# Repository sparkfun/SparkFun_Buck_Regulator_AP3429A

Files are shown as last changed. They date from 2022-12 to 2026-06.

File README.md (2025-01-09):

SparkFun AP3429A Buck Regulator Breakouts
========================================

<p align="center">
  <a href="https://github.com/sparkfun/SparkFun_Buck_Regulator_AP3429A/issues" alt="Issues">
    </a>
  <a href="https://github.com/sparkfun/SparkFun_Buck_Regulator_AP3429A/actions" alt="Actions">
    </a>
  <a href="https://github.com/sparkfun/SparkFun_Buck_Regulator_AP3429A/blob/main/LICENSE.md" alt="License">
    </a>
  <a href="https://twitter.com/intent/follow?screen_name=sparkfun">
    </a>
</p>

| [3.3V Buck Regulator (COM-21337)](https://www.sparkfun.com/products/21337) | [1.8V Buck Regulator (COM-21338)](https://www.sparkfun.com/products/21338) |
| --- | --- |
| SparkFun Buck Regulator Breakout - 3.3V (AP3429A) (https://www.sparkfun.com/products/21337) | SparkFun Buck Regulator Breakout - 1.8V (AP3429A) (https://www.sparkfun.com/products/21338) |

These buck regulator boards feature the AP3429A from [Diodes Inc.](https://www.diodes.com/), a 2A DC-DC buck converter with a wide input voltage range of 2.7V to 5.5V. The boards are configured to provide a regulated **3.3V** or **1.8V** output, which is controlled by an `EN` *(enable)* pin and indicated by a red power LED. A pre-assembled screw terminal and 0.1" spaced PTH pins are available to connect the input and output power of the boards. Additionally, there is the option to solder on a [barrel jack](https://www.sparkfun.com/products/119) for an [external power supply](https://www.sparkfun.com/categories/308). To dissipate excess heat, a copper pad is provided to attach a heat sink to the bottom of the board.

*The primary differences between these boards are their regulated output voltage (**1.8V** and **3.3V**) and the configured UVLO (**2.7V** and **3.9V**, respectively).*

Repository Contents
-------------------

* **[/docs](/docs/)** - Online documentation files
    * [board_files](/docs/board_files/) - Files for the product design
        * [Eagle design files](/docs/board_files/eagle_files.zip) (.zip)
        * [Schematic](/docs/board_files/schematic.pdf) (.pdf)
        * [Dimensions](/docs/board_files/dimensions.pdf) (.pdf)
    * [component_documentation](/docs/component_documentation/) - Datasheets for hardware components
    * [img/hookup_guide/](/docs/img/hookup_guide/) - Images for hookup guide documentation
* **[/Hardware](/Hardware/)** - Eagle design files (.brd, .sch)

Documentation
--------------
* **[Hookup Guide (mkdocs)](http://docs.sparkfun.com/SparkFun_Buck_Regulator_AP3429A/)** - Hookup Guide for the AP3429A Buck Regulator Breakouts

Product Variants
----------------
* **AP63357** - 5V Buck Regulators
    * COM-21255: [SparkFun Buck Regulator Breakout - 5V (AP63357DV)](https://www.sparkfun.com/products/21255)
    * COM-21256: [SparkFun BabyBuck Regulator Breakout - 5V (AP63357DV)](https://www.sparkfun.com/products/21256)
* **AP63203** - 3.3V Buck Regulators
    * COM-18356: [SparkFun Buck Regulator Breakout - 3.3V (AP63203)](https://www.sparkfun.com/products/18356)
    * COM-18357: [SparkFun BabyBuck Regulator Breakout - 3.3V (AP63203)](https://www.sparkfun.com/products/18357)
* **AP3429A** - 3.3V & 1.8V Buck Regulators
    * COM-21337: [SparkFun Buck Regulator Breakout - 3.3V (AP3429A)](https://www.sparkfun.com/products/21337)
    * COM-21338: [SparkFun Buck Regulator Breakout - 1.8V (AP3429A)](https://www.sparkfun.com/products/21338)

Version History
---------------
* [v01](https://github.com/sparkfun/SparkFun_Buck_Regulator_AP3429A/releases/tag/v01) - Initial Release

License Information
-------------------

This product is _**open source**_! 

Please review the LICENSE.md file for license information. 

If you have any questions or concerns about licensing, please contact technical support on our [SparkFun forums](https://forum.sparkfun.com/viewforum.php?f=152).

Distributed as-is; no warranty is given.

- Your friends at SparkFun.

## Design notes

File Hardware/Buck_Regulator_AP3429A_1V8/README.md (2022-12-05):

SparkFun <PRODUCT NAME> Design Files
=====================================

The .sch and .brd files hare are Eagle CAD schematic and PCB design files from SparkFun Electronics.
A freeware version of Autodesk Eagle can be found [here](https://www.autodesk.com/products/eagle/free-download).

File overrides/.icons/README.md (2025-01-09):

.icons directory
====================
This folder should contain branding logos for the product documentation

## General Images
- `sfe-logo.svg` - SparkFun flame logo
- `kicad-primary.svg` - Full KiCad logo

## Directory
- `logo` - Other available logos

## SVG Optimizer
- [Remove meta data from svg](https://jakearchibald.github.io/svgomg/)

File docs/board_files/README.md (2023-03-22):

board_files directory
====================

1. A `dimensions*.pdf` file containing the boards' measurements.
2. A `schematic*.pdf` file containing the boards' schematics.
3. An `eagle_files*.zip` folder containing the Eagle CAD schematics (`*.sch`) and PCB design (`*.brd`) files.
    * A freeware version of Autodesk Eagle can be found [here](https://www.autodesk.com/products/eagle/free-download).

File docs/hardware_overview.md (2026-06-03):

---
icon: material/cog
---

## Board Dimensions

The board dimensions are illustrated in the drawing below; the listed measurements are in inches.

<figure markdown>
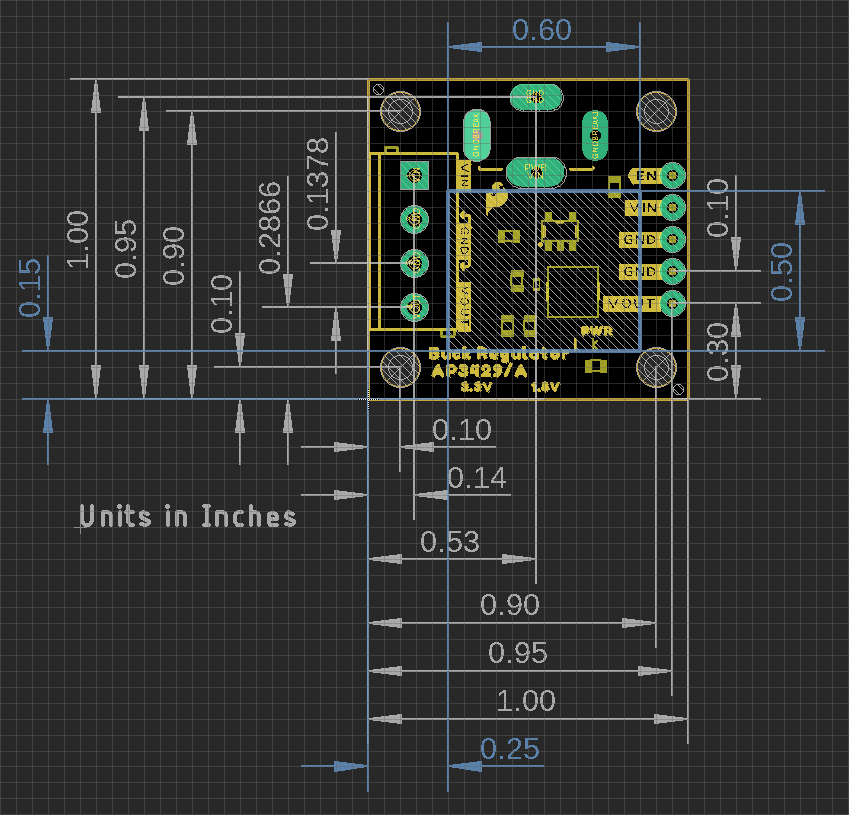
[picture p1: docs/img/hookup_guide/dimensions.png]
Board Dimensions

<figcaption markdown>
[Board dimensions (PDF)](../board_files/dimensions.pdf) for the AP3429A Buck Regulator breakout boards, in inches.
</figcaption>
</figure>

??? tip "Need more measurements?"
	For more information about the board's dimensions, users can download the [eagle files](../board_files/eagle_files.zip) for the board. These files can be opened in Eagle and additional measurements can be made with the dimensions tool.

	??? info ":octicons-download-16:{ .heart } Eagle - Free Download!"
		Eagle is a [CAD]("computer-aided design") program for electronics that is free to use for hobbyists and students. However, it does require an account registration to utilize the software.

		<article style="text-align: center;" markdown>
		[Download from<br>:autodesk-primary:{ .enlarge-logo }](https://www.autodesk.com/products/eagle/free-download "Go to downloads page"){ .md-button .md-button--primary width="250px" }
		</article>
	
	??? info ":straight_ruler: Dimensions Tool"
		This video from Autodesk demonstrates how to utilize the dimensions tool in Eagle, to include additional measurements:

		<article style="text-align: center;" markdown>
		<div class="video">
		<iframe src="https://www.youtube.com/embed/dZLNd1FtNB8" title="EAGLE Dimension Tool" frameborder="0" allow="accelerometer; autoplay; clipboard-write; encrypted-media; gyroscope; picture-in-picture" allowfullscreen></iframe>
		</div>
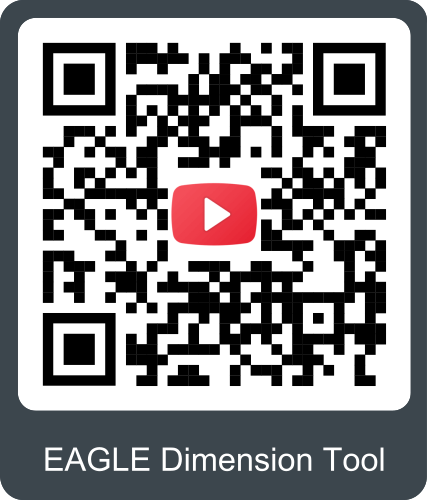
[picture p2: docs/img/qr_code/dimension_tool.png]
QR code to play video
		
		</article>

## Power

Users are provided with [PTH](https://en.wikipedia.org/wiki/Through-hole_technology "Plated Through Holes") to connect their external power supply, the output voltage from the board, and the [`EN`](#power-control "Enable") power control pin for the buck regulator. The AP3429A buck regulator has an input voltage range is **2.7V** to **5.5V**. Each board has a different regulated output voltage (**1.8V** or **3.3V**) and input voltage range. *(These are step-down DC/DC converters and cannot step-up or boost the voltage output.)*

<figure markdown>
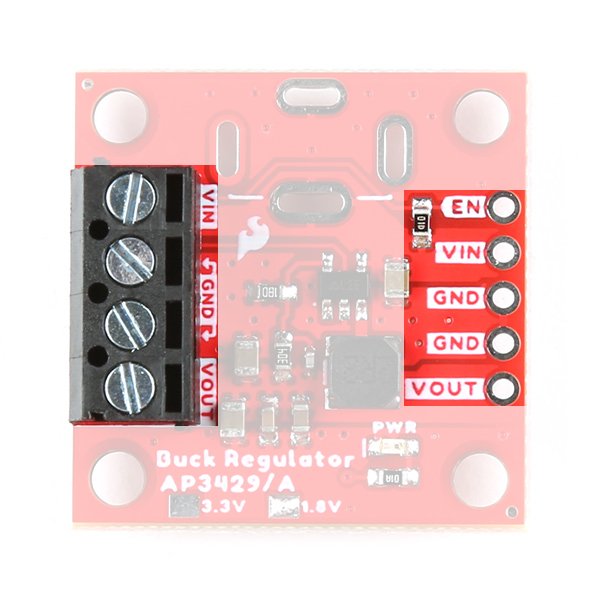
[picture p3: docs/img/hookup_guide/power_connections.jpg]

<figcaption markdown>
The power connections on the AP3429A Buck Regulator Breakout boards.
</figcaption>
</figure>

Below, is a general summary of the circuitry on the board:

* **`VIN`** - Power supply input
    * 1.8V Buck Regulator: **<span style="color:red">2.7V</span> to 5.5V**
    * 3.3V Buck Regulator: **<span style="color:green">3.9V</span> to 5.5V**
* **`EN`** - Enables the power output of the board
	* Has an input voltage range up to **5.5V**
	* Must be pulled `HIGH` above **1.5V** to enable the power output. Otherwise, if pulled `LOW` below 0.4V, the device shuts down.
* **`VOUT`** - Regulated 1.8V or 3.3V output *(up to 2A)*
* **`GND`** - The common ground or the 0V reference for the board

!!! info
	For more details, users can reference the [schematic](../board_files/schematic.pdf) and the [datasheets of the individual components](../resources/#hardware-component-documentation) in the power circuitry.

??? tip "Maximum Load Current"
	While the IC is rated up to 2A, we were able to squeeze a little extra juice for a maximum load of ~2.2A. Anything near 2.4A, the board will start to struggle and automatically shut down.
	
	***Disclaimer:** We don't recommend that users expect to be able to load the boards with a maximum 2.2A, as we are not sure how this may affect the lifespan of the board. We just want users to know that they may have an extra margin of safety on their peak load.* 

??? tip "Quiescent Current Draw"
    Users should expect a nominal quiescent current draw of ~90&micro;A from the board. For a lower quiescent current, users can disable the power output and/or modify the board by removing the pull-up resistor on the [`EN`](#power-control "enable") pin.

	<div class="grid cards" markdown>

	-	Measured Values

		---

		<table style="text-align: center;" markdown>
		<tr markdown>
		<td rowspan="2" align="center" style="vertical-align:middle;" markdown>
		Input<br>Voltage (V)
		</td>
		<td colspan="2" align="center" style="vertical-align:middle;" markdown>
		I~q~ (&micro;A)<br>*Power Disabled*
		</td>
		<td colspan="2" align="center" markdown>
		I~q~ (&micro;A)<br>*Power Enabled*
		</td>
		</tr>
		<tr markdown>
		<td align="center" markdown>**1.8V**</td>
		<td align="center" markdown>**3.3V**</td>
		<td align="center" markdown>**1.8V**</td>
		<td align="center" markdown>**3.3V**</td>
		</tr>
		<tr markdown>
		<td align="center" markdown>5.0</td>
		<td markdown>49.34</td>
		<td markdown>49.58</td>
		<td markdown>85.15</td>
		<td markdown>97.48</td>
		</tr>
		<tr markdown>
		<td align="center" markdown>4.5</td>
		<td markdown>44.60</td>
		<td markdown>44.81</td>
		<td markdown>83.32</td>
		<td markdown>96.00</td>
		</tr>
		<tr markdown>
		<td align="center" markdown>4.2</td>
		<td markdown>41.51</td>
		<td markdown>41.71</td>
		<td markdown>82.64</td>
		<td markdown>95.27</td>
		</tr>
		<tr markdown>
		<td align="center" markdown>3.9</td>
		<td align="center" markdown>---</td>
		<td markdown>38.70</td>
		<td align="center" markdown>---</td>
		<td markdown>95.03</td>
		</tr>
		<tr markdown>
		<td align="center" markdown>3.7</td>
		<td markdown>36.60</td>
		<td markdown>36.76</td>
		<td markdown>81.88</td>
		<td markdown>94.87</td>
		</tr>
		<tr markdown>
		<td align="center" markdown>3.3</td>
		<td markdown>32.70</td>
		<td markdown>32.84</td>
		<td markdown>81.23</td>
		<td markdown>338.12</td>
		</tr>
		<tr markdown>
		<td align="center" markdown>3.0</td>
		<td markdown>29.82</td>
		<td align="center" markdown>N/A</td>
		<td markdown>80.59</td>
		<td align="center" markdown>N/A</td>
		</tr>
		<tr markdown>
		<td align="center" markdown>2.7</td>
		<td markdown>27.06</td>
		<td align="center" markdown>N/A</td>
		<td markdown>79.58</td>
		<td align="center" markdown>N/A</td>
		</tr>
		</table>

		*The values in the table above, were measured with a [Power Profiler Kit II](https://www.nordicsemi.com/Products/Development-hardware/Power-Profiler-Kit-2) and averaged over a 10s period.*

	-	Pull-Up Resistor Modification

		---

		<figure markdown>
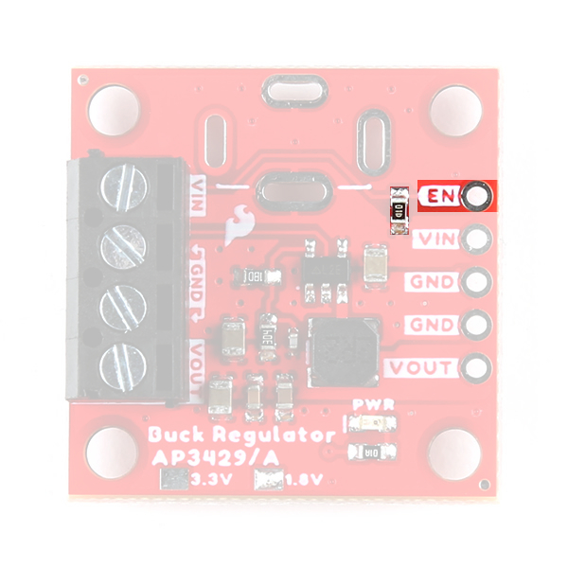
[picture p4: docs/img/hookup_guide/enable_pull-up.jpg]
		
		<figcaption markdown>
		Pull-up resistor on the AP3429A Buck Regulator Breakout boards.
		</figcaption>
		</figure>
		
		!!! danger
			Modifying a board to remove the pull-up resistor, requires advanced soldering skills. Users should **not** attempt this modification unless it is absolutely, necessary and they are confident in their skills because the board can be permanently damaged.

	</div>

### Power Connections

There are several options available for users to connect power to and from their AP3429A buck regulator breakout board.

<article style="text-align: center;" markdown>

| Input Options  | Output Power | Enable Pin |
| :--- | :--- | :--- |
| <ul><li>PTH Pins</li><li>Screw Terminal</li><li>Barrel Jack</li></ul> | <ul><li>PTH Pins</li><li>Screw Terminal</li></ul> | <ul><li>PTH Pins</li></ul> |

</article>

#### PTH Pins

Five [PTH](https://en.wikipedia.org/wiki/Through-hole_technology "Plated Through Holes") pins are provided for an external power supply, the output voltage from the board, and the [`EN`](#power-control "enable") power control pin. The holes are spaced 0.1", to be compatible with [headers](https://www.sparkfun.com/categories/381 "Click here for a full selection of our available headers") and [breadboards](https://www.sparkfun.com/categories/302 "Click here for a full selection of our available breadboards").

<figure markdown>
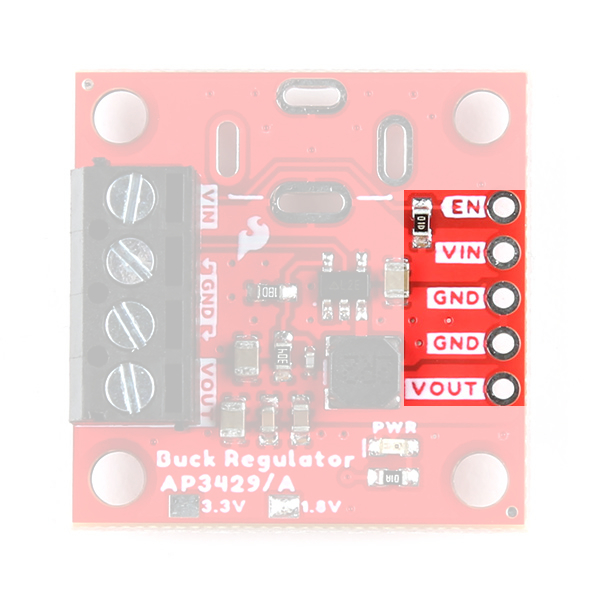
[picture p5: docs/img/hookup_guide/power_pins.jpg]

<figcaption markdown>
The PTH power pins on the AP3429A Buck Regulator Breakout boards.
</figcaption>
</figure>

#### Screw Terminals

A screw terminal is provided for users, as a non-permanent solution, to easily connect wires to the board.

!!! info "Compatible Wire Sizes"
	The screw terminal is compatible with wire sizes from **26AWG** to **16AWG**.

<figure markdown>
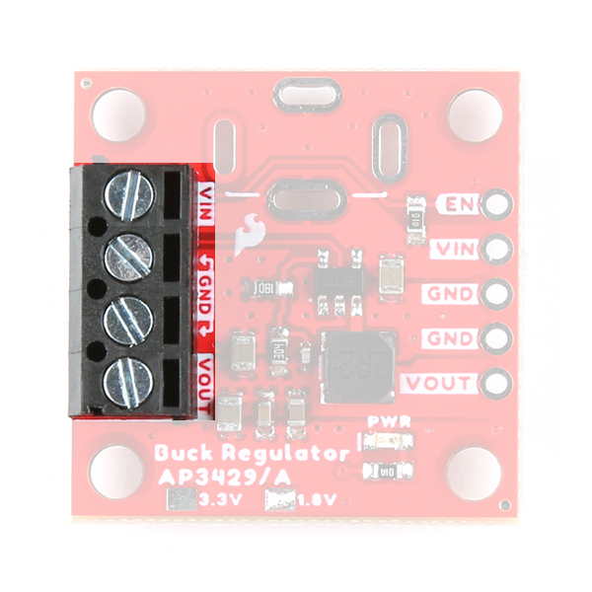
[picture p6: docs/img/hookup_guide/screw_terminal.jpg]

<figcaption markdown>The screw terminal on the AP3429A Buck Regulator Breakout boards.</figcaption>
</figure>

#### Barrel Jack

PTH *(slots)* are provided for users to add a [barrel jack connector](https://www.sparkfun.com/products/119) to the top or bottom of the board. This provides users with an alternative method to connect a power supply to their board.

!!! info "Barrel Jack Size"
	Our recommended [barrel jack connector](https://www.sparkfun.com/products/119) is a 5.5mm barrel jack.

<div class="grid cards" markdown>

-   <figure markdown>
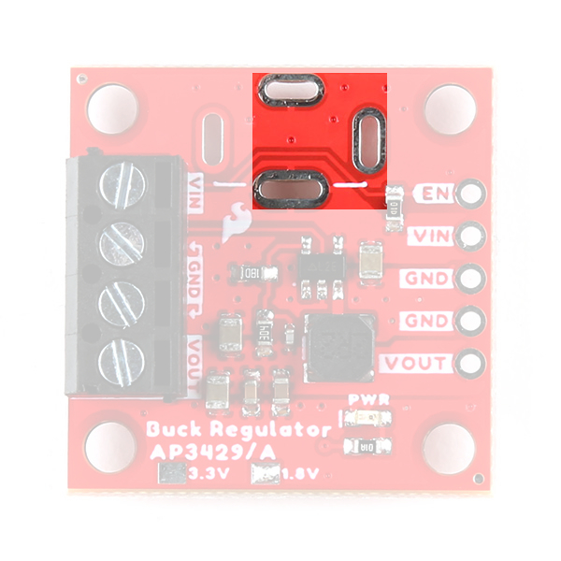
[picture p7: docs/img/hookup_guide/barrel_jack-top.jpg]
	
	<figcaption markdown>
    The plated slots for a barrel jack connector on the top side of the AP3429A Buck Regulator Breakout boards.
    </figcaption>
	</figure>

-   <figure markdown>
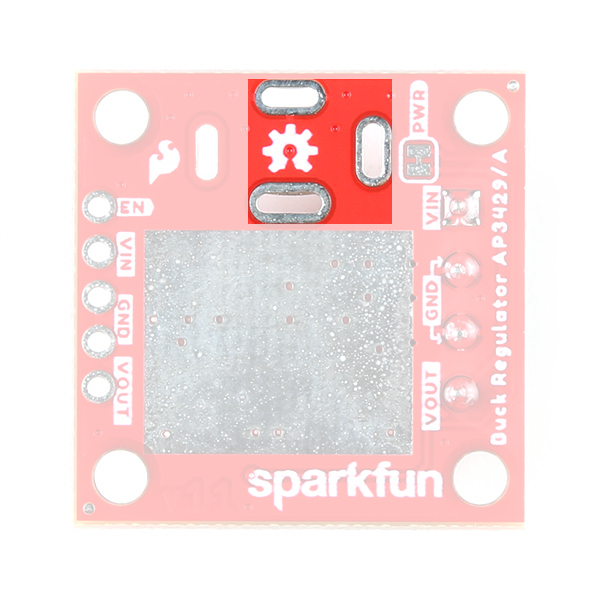
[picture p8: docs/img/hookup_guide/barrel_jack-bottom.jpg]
	
	<figcaption markdown>
	The plated slots for a barrel jack connector on the bottom side of the AP3429A Buck Regulator Breakout boards.
	</figcaption>
	</figure>

</div>

### Power LED

The red, power (`PWR`) LED will light up when the switching power output is enabled. However, the LED can be disabled for low-power applications by cutting the [jumper](#jumper).

<figure markdown>
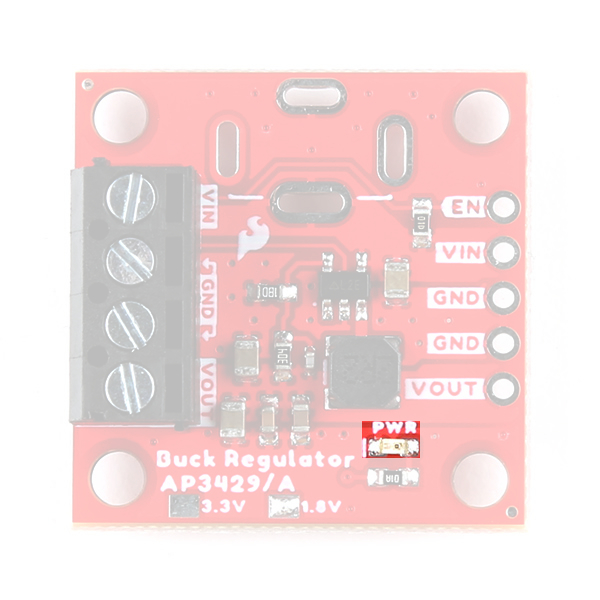
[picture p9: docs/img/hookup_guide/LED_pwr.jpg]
Power LED

<figcaption markdown>
The `PWR` status LED indicator for the AP3429A Buck Regulator Breakout boards.
</figcaption>
</figure>

### Power Control

There is an enable pin (`EN`) to control the output voltage *(i.e. on/off)*, with a typical threshold voltage of **1.5V** and a range up to **5.5V**

* Users should pull the `EN` pin high *(above 1.5V)* to enable the switching power output and pull the pin low *(below 0.4V)* to disable it.
	* Users can connect the `EN` pin to `VIN` to override the [UVLO]("Undervoltage Lockout") threshold.

!!! info "Default Configuration"
	On our boards, the `EN` pin is pulled `HIGH` and the power output from the board is enabled by default.

<figure markdown>
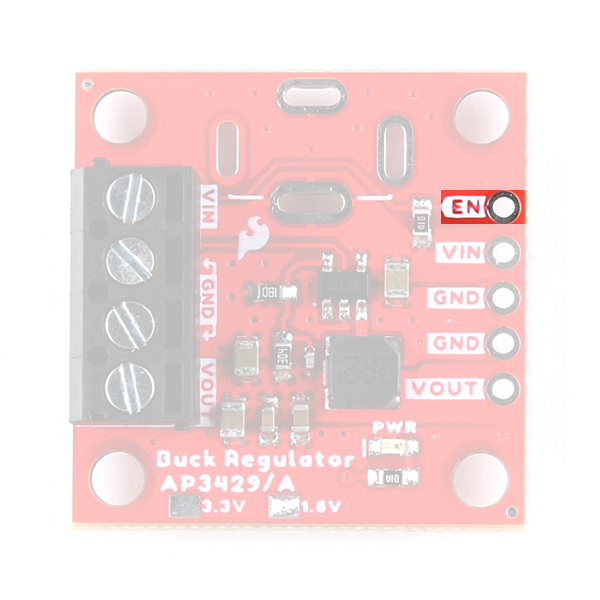
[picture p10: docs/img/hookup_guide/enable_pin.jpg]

<figcaption markdown>
Enable pin on the AP3429A Buck Regulator Breakout boards.
</figcaption>
</figure>

## :fontawesome-solid-microchip:&nbsp;AP3429A

The [AP3429A](../component_documentation/AP3429A.pdf) from [Diodes Incorporated](https://www.diodes.com/), is a 2A DC-DC buck converter with a wide input voltage range of 2.7V to 5.5V. Under a no-load condition, the quiescent current is 90&micro;A; and when disabled, the device shutdown supply current is less than 1&micro;A.

<div class="grid cards" markdown>

-   Features:

    * VIN: 2.7V to 5.5V
    * VOUT: 0.6V to VIN
    * 2A Continuous Output Current
    * 90&micro;A No-Load Quiescent Current
    * 1MHz Switching Frequency
    * Protection Circuitry
        * Undervoltage Lockout (UVLO)
        * Input Overvoltage Protection
        * Over Current Protection
            * Cycle-by-Cycle Peak Current Limit
        * Thermal Shutdown

-	<figure markdown>
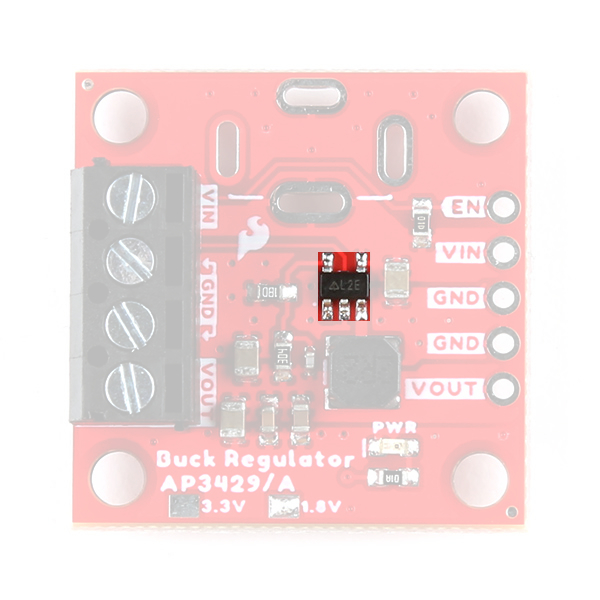
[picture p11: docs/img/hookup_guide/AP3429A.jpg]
	
	<figcaption markdown>
	AP3429A chip on the AP3429A Buck Regulator Breakout boards.
	</figcaption>
	</figure>

</div>

!!! info
	For more details, please refer to the [AP3429A datasheet](../component_documentation/AP3429A.pdf) and [application note](../component_documentation/AN_AP3428.pdf).

??? info "Power Efficiency"
	Users should expect a power efficiency close to the chart presented in the [datasheet](../component_documentation/AP3429A.pdf) *(i.e. ~80% with smaller loads and up to +90% with larger loads)*. It should be noted that the efficiency varies with the load current and cooling.

	<figure markdown>
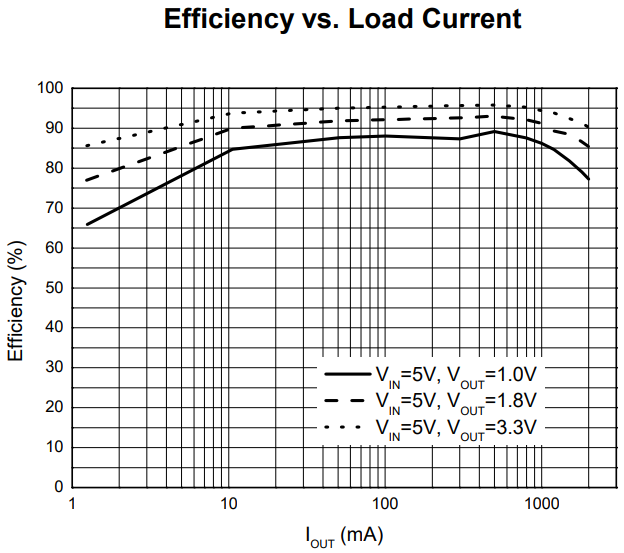
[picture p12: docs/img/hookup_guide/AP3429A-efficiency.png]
	
	<figcaption markdown>
	Figure from the [datasheet](../component_documentation/AP3429A.pdf).
	</figcaption>
	</figure>

??? info "Circuit Protection"
	The AP3429A features the following circuit protections:

	=== "Undervoltage Lockout"
		We have found the undervoltage lockout to trigger ~2.7V for the 1.8V breakout and ~3.9V for the 3.3V breakout board.
	
	=== "Over Current Protection"
		
		* If the peak current is higher than the current limit threshold, it will enter cycle-by-cycle current limit mode.
		* If short is detected, when the feedback voltage (V~FB~) drops under 0.3V, the AP3429 will turn off power output until the `VIN` or `EN` is cycled again to release it.
			* Once V~FB~ rises over 0.3V, the AP3429A automatically recovers to normal operation.
	
	=== "Over Voltage Protection"
		* **Output:** When `VOUT` exceeds 120% of the regulation level, the output power will be disabled until `VIN` or `EN` is cycled.
		* **Input:** When the input voltage is near 6.25V, the IC will shut down until the input voltage drops back down below 6V.

### Output Voltage Configuration

The output voltage from the AP3429A, is determined by the voltage divider on the feedback loop, as discussed in the [application note](../component_documentation/AN_AP3428.pdf).

??? note "Application Note"
	While the [application note](../component_documentation/AN_AP3428.pdf) only lists the AP3428 buck converter, Diodes Incorporated has assured us that it is still applicable to the AP3429A.

$$
V_{OUT} =  0.6 * \frac{ (R_1 + R_2) }{ R_2 }
$$

Where, R~1~ and R~2~ are the resistors in the feedback loop:

<figure markdown>
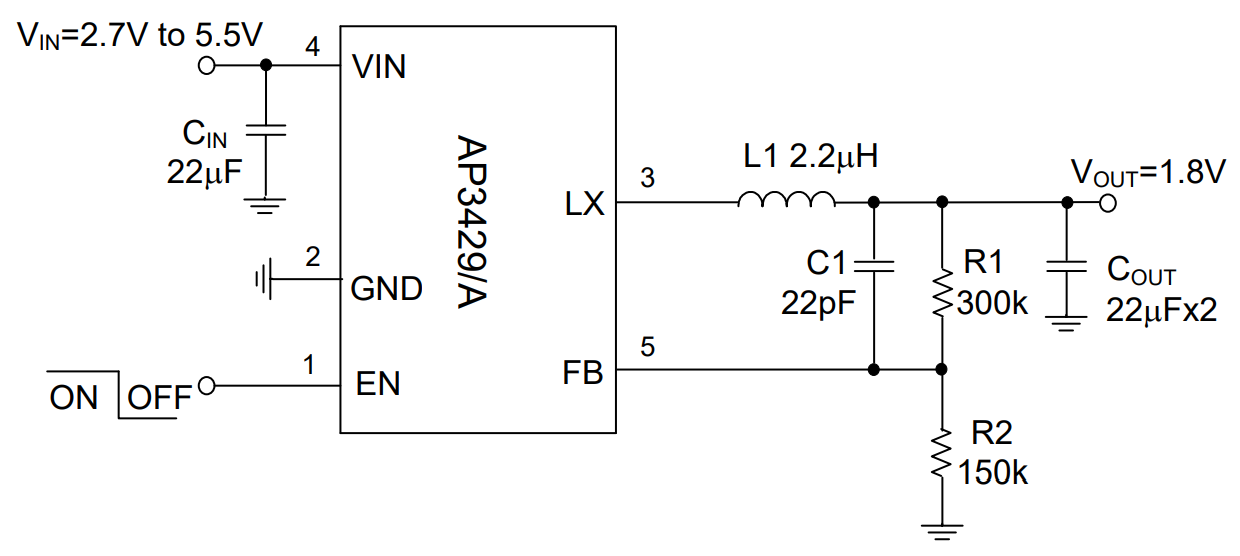
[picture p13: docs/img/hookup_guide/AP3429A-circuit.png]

<figcaption markdown>
Example circuit for the AP3429A.
</figcaption>
</figure>

## Output Voltage Indicator

Since it would be difficult to differentiate the voltage output based on the small SMD parts, we provide a simple indicator for the configured output voltage of each board.

<div class="grid cards" markdown>

-   <figure markdown>
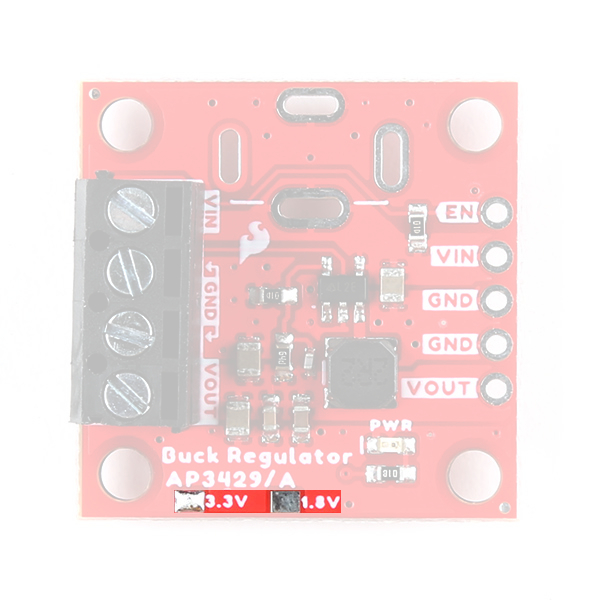
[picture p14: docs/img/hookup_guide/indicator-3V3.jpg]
	
	<figcaption markdown>
    The output voltage indicator for the **3.3V** Buck Regulator Breakout.
    </figcaption>
	</figure>

-   <figure markdown>
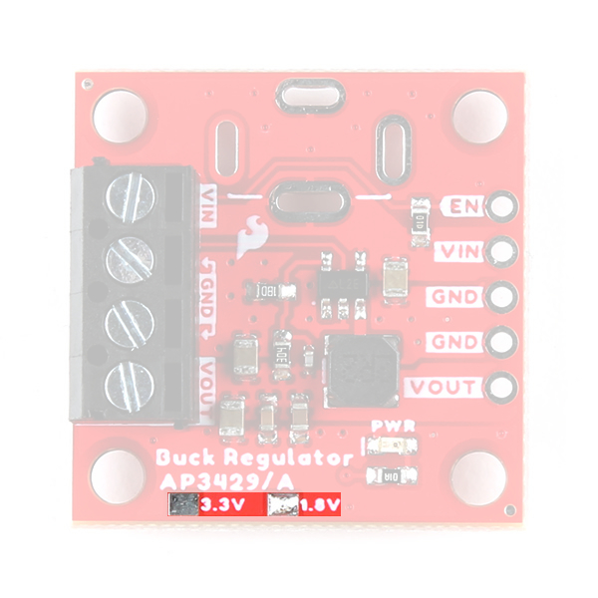
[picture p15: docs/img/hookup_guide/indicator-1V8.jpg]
	
	<figcaption markdown>
	The output voltage indicator for the **1.8V** Buck Regulator Breakout.
	</figcaption>
	</figure>

</div>

## Heat Sink Pad

A 0.5" x 0.6" platted copper pad is provided on the back of the boards, where users can add a heat sink to dissipate excess heat generated by the AP3429A. The pad can accommodate the [copper heatsink](https://www.sparkfun.com/products/18704) in our catalog.

??? info "Thermal Shutdown Temperature"
	The AP329A has a 160&deg;C (320&deg;F) thermal shutdown temperature. The AP3429A will restart automatically when the junction temperature decreases to +130°C.

<figure markdown>
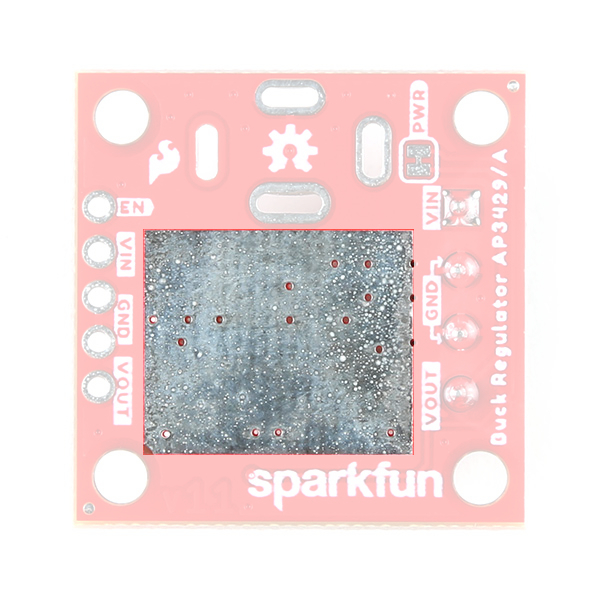
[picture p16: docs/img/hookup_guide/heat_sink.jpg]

<figcaption markdown>
Heat sink pad on the back of the AP3429A Buck Regulator Breakout boards.
</figcaption>
</figure>

??? tip "Thermal Characteristics"
	Below are charts depicting the thermal performance of the AP3429A Buck Regulator Breakout boards that users should expect. These values were measured at 200mA steps for input voltages between 4 - 5.5V.

	=== "1.8V w/o Heatsink"
		<figure markdown>
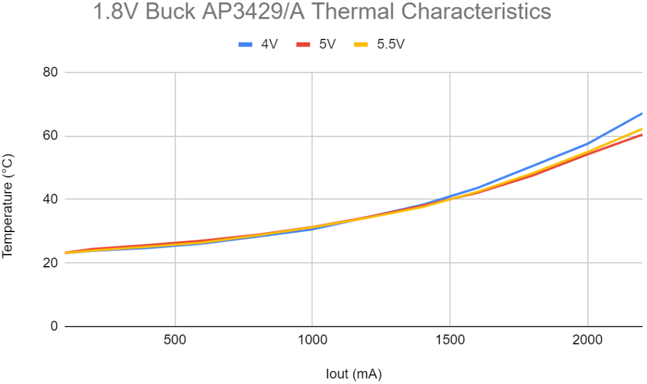
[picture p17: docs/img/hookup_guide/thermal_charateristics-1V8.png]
		
		<figcaption markdown>
		Thermal characteristics of the 1.8V Buck Regulator Breakout board without a heatsink.
		</figcaption>
		</figure>
	
	=== "1.8V w/ Heatsink"
		<figure markdown>
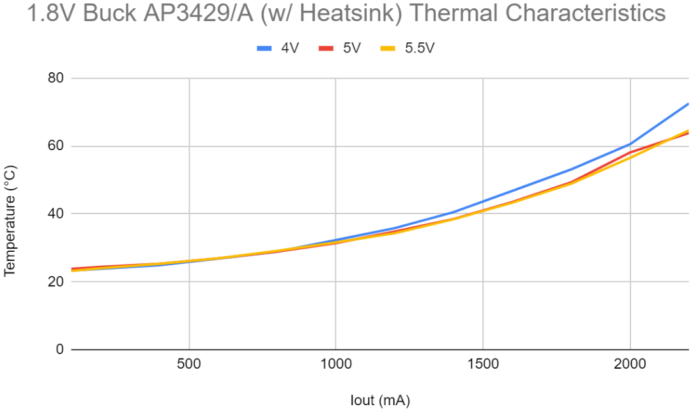
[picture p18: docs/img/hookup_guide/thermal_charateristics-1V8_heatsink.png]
		
		<figcaption markdown>
		Thermal characteristics of the 1.8V Buck Regulator Breakout board with a heatsink.
		</figcaption>
		</figure>

	=== "3.3V w/o Heatsink"
		<figure markdown>
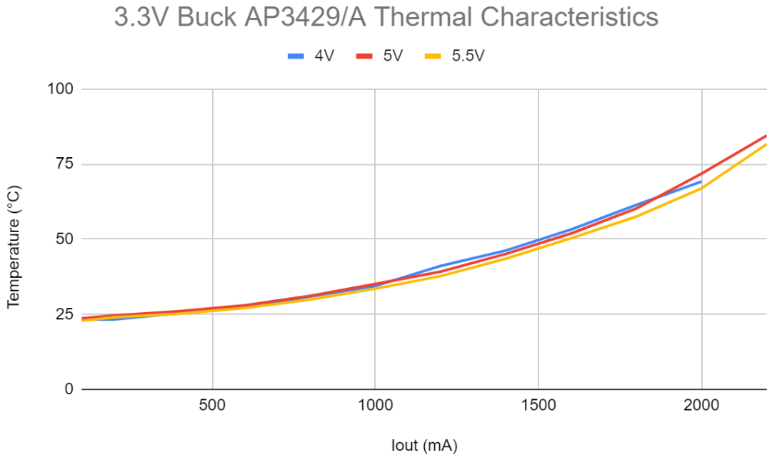
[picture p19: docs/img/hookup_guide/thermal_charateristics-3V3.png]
		
		<figcaption markdown>
		Thermal characteristics of the 3.3V Buck Regulator Breakout board without a heatsink.
		</figcaption>
		</figure>

	=== "3.3V w/ Heatsink"
		<figure markdown>
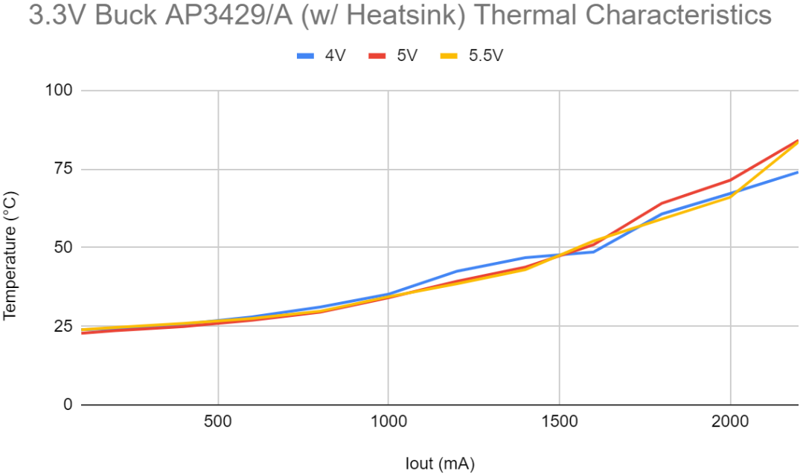
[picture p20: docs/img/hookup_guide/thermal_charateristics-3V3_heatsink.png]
		
		<figcaption markdown>
		Thermal characteristics of the 3.3V Buck Regulator Breakout board with a heatsink.
		</figcaption>
		</figure>

## Jumper

??? note "Never modified a jumper before?"
	Check out our <a href="https://learn.sparkfun.com/tutorials/664">Jumper Pads and PCB Traces tutorial</a> for a quick introduction!
	<p align="center">
		<a href="https://learn.sparkfun.com/tutorials/664">How to Work with Jumper Pads and PCB Traces<br>
		Tutorial's thumbnail</a>
	</p>

There is a jumper on the back of the board that can be used to easily modify a hardware connection on the board.

* **PWR** - This jumper can be used to remove power to the `PWR` LED.

<figure markdown>
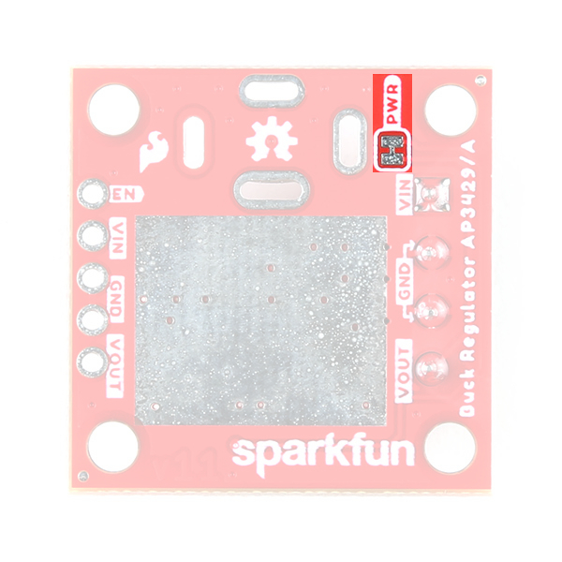
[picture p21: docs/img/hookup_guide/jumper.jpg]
Jumpers

<figcaption markdown>
The LED jumper on the back of the AP3429A Buck Regulator Breakout boards.
</figcaption>
</figure>

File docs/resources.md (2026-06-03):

## Product Resources

<section class="grid cards show" style="grid-template-columns: repeat(auto-fit,minmax(8rem,1fr));" markdown>

- **Composite (Both Boards)**

    ---

    * :sfe-logo: [Product Category](https://www.sparkfun.com/categories/tags/buck-)
    * :fontawesome-solid-file-pdf: [Board Dimensions](./board_files/dimensions.pdf)
    * Component Documentation
        * :fontawesome-solid-file-pdf: [AP3429A Datasheet](./component_documentation/AP3429A.pdf)
        * :fontawesome-solid-file-pdf: [Application Note](./component_documentation/AN_AP3428.pdf)
    * :material-folder-cog: Design Files:
        * :fontawesome-solid-file-pdf: [Schematic](./board_files/schematic.pdf)
        * :material-folder-zip: [Eagle Files](./board_files/eagle_files.zip)
    * :material-github: [Hardware Repo](https://github.com/sparkfun/SparkFun_Buck_Regulator_AP3429A)

- **3.3V Buck Regulator Breakout - (AP3429A)**

    ---

    * :sfe-logo: [Product Page](https://www.sparkfun.com/products/21337)
    * :material-folder-cog: Design Files:
        * :fontawesome-solid-file-pdf: [Schematic](./board_files/schematic-Buck3V3.pdf)
        * :material-folder-zip: [Eagle Files](./board_files/eagle_files-Buck3V3.zip)

- **1.8V Buck Regulator Breakout - (AP3429A)**

    ---

    * :sfe-logo: [Product Page](https://www.sparkfun.com/products/21338)
    * :material-folder-cog: Design Files:
        * :fontawesome-solid-file-pdf: [Schematic](./board_files/schematic-Buck1V8.pdf)
        * :material-folder-zip: [Eagle Files](./board_files/eagle_files-Buck1V8.zip)

</section>

### Additional Resources

* [DC/DC Converter Product Category](https://www.sparkfun.com/categories/tags/dc-dc-converter)
* :material-account-supervisor: [SparkFun Technical Assistance](https://www.sparkfun.com/technical_assistance)

## 🏭&nbsp;Manufacturer's Resources
Diodes Incorporated also provides great resources for the AP3429A Buck Regulator:

* [AP3429A Product Page](https://www.diodes.com/part/view/AP3429)
    * :material-file-document-multiple: [Technical Documentation](ps://www.diodes.com/part/view/AP3429/#tab-details)
* :material-head-question: [Technical Support Page](https://www.diodes.com/about/contact-us/technical-support/)

<article style="text-align: center;" markdown>
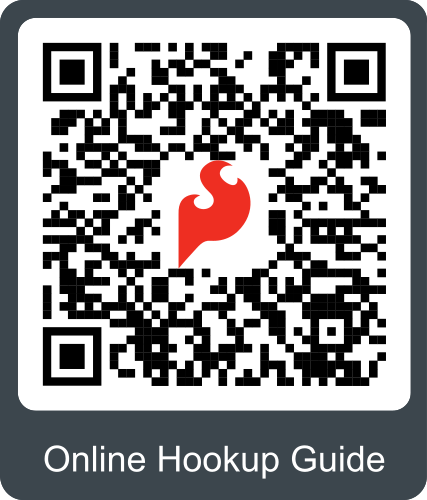
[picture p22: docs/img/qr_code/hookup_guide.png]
QR code to the hookup guide

</article>

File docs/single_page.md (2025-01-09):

---
hide:
  - navigation
  - toc
icon: fontawesome/solid/scroll
---

--8<-- "./docs/getting_started.md:5"

# Hardware Overview
--8<-- "./docs/hardware_overview.md:5"

# Hardware Assembly
--8<-- "./docs/hardware_assembly.md:5"

# Troubleshooting Tips
--8<-- "./docs/troubleshooting_tips.md:5"

# Test Setup
--8<-- "./docs/load_test.md:5"

# Resources
--8<-- "./docs/resources.md"

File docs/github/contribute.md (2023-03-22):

# Contribute: Make an Augmentation!
Spot an improvement opportunity? Feel free to contribute to our open-source design and documentation. 

## :material-file-document-multiple:&nbsp;Improve our Documentation
All of this documentation can be modified by you! Please help us make it better.

* These pages are contained in the [`docs` folder](https://github.com/sparkfun/SparkFun_Buck_Regulator_AP3429A/tree/main/docs) of the [SparkFun AP3429A Buck Regulator repository](https://github.com/sparkfun/SparkFun_Buck_Regulator_AP3429A).

<!-- ### :material-source-pull:&nbsp;Submit a Correction -->
### Submit a Correction

1. With a GitHub account, [fork this repository](https://github.com/sparkfun/SparkFun_Buck_Regulator_AP3429A/fork).
2. Add your corrections or improvements to the markdown file.
3. File a pull request with your changes, and enjoy making the ~~words~~ ~~worlds~~ world a better place.
	* Once received, the documentation specialist will automatically be notified.
	* We will review your suggested improvements to make sure they are correct and fit within our documentation standards.

## :material-cog:&nbsp;Improve our Hardware Design
All of our designs are open-source! Please help us make it better.

* Our board design files are contained in the [`Hardware` folder](https://github.com/sparkfun/SparkFun_Buck_Regulator_AP3429A/tree/main/Hardware) of the [SparkFun AP3429A Buck Regulator repository](https://github.com/sparkfun/SparkFun_Buck_Regulator_AP3429A).

<!-- ### :material-source-pull:&nbsp;Submit a Design Enhancement -->
### Submit a Design Enhancement

1. With a GitHub account, [fork this repository](https://github.com/sparkfun/SparkFun_Buck_Regulator_AP3429A/fork).
2. Add your design augmentation(s)
3. File a pull request with your changes, and enjoy making the ~~words~~ ~~worlds~~ world a better place.
	1. Once received, the engineer in charge of the original design will automatically be notified.
	2. We will review your suggested improvement(s) to verify that they are within our board design standards and meet our product design requirements.
	3. If approved, we will flag these changes for our next board revision. Congrats! 🍻

		!!! info
			Even if your suggestion is accepted, these changes may not be immediately available for purchase. We may have to cycle through our current product inventory first.

## Contributors&nbsp;:clap:
Let's provide some recognition to the contributors for this project!

GitHub Contributors Image
<br>


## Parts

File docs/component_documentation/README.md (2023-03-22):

component_documentation directory
====================

A copy of the datasheets, user manuals, programming guides, etc. of the major electrical components on the board.

* DC-DC Buck Converter: [AP3429A](AP3429A.pdf) (PDF)
    * Application Note: [AN_AP3428](AN_AP3428.pdf) (PDF)
        * *Although the application note is listed for the AP3428, Diodes Inc. provided this document for configuring the output voltage of the AP3429A. The application note is interchangeable between the two ICs.*

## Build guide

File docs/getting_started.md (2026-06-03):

---
icon: material/book-open-page-variant
---

# Getting Started

!!! note
	The SparkFun Buck Regulator Breakout - [3.3V (AP3429A)](https://www.sparkfun.com/products/21337) and [1.8V (AP3429A)](https://www.sparkfun.com/products/21338) have similar features to our previous [buck regulators (AP63203 & AP63357)](https://www.sparkfun.com/categories/tags/buck-).

## Introduction
These boards feature the AP3429A from [Diodes Inc.](https://www.diodes.com/), a 2A step-down DC-DC converter with an input voltage range of 2.7V to 5.5V. They are configured to provide a regulated **3.3V** or **1.8V** output, which is controlled by an `EN` *(enable)* pin and indicated by a red power LED. A pre-assembled screw terminal and 0.1" spaced PTH pins are available to connect the input and output power of the boards. Additionally, there is the option to solder on a [barrel jack](https://www.sparkfun.com/products/119) for an [external power supply](https://www.sparkfun.com/categories/308). To dissipate excess heat, a 0.5" x 0.6" copper pad is provided to attach a heat sink to the bottom of the board.

<section class="grid cards col-2"markdown>

-	<a href="https://www.sparkfun.com/products/21337">
	**3.3V Buck Regulator Breakout - AP3429A**<br>
	**SKU:** COM-21337

	---

	<figure markdown>
	Product image
	</figure>
	</a>

	This board provides a regulated **3.3V** output with an input voltage range of **3.9V - 5.5V**.

	<article style="text-align: center;" markdown>
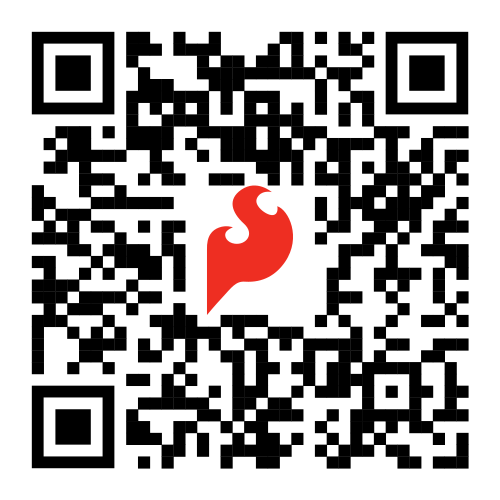
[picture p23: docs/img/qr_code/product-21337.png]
QR code to product page
	[&nbsp;&nbsp;&nbsp;Purchase from SparkFun :fontawesome-solid-cart-plus:{ .heart }](https://www.sparkfun.com/products/21337){ .md-button .md-button--primary }
	</article>

-	<a href="https://www.sparkfun.com/products/21338">
	**1.8V Buck Regulator Breakout - AP3429A**<br>
	**SKU:** COM-21338

	---

	<figure markdown>
	Product image
	</figure></a>

	This board provides a regulated **1.8V** output with an input voltage range of **2.7V - 5.5V**.

	<article style="text-align: center;" markdown>
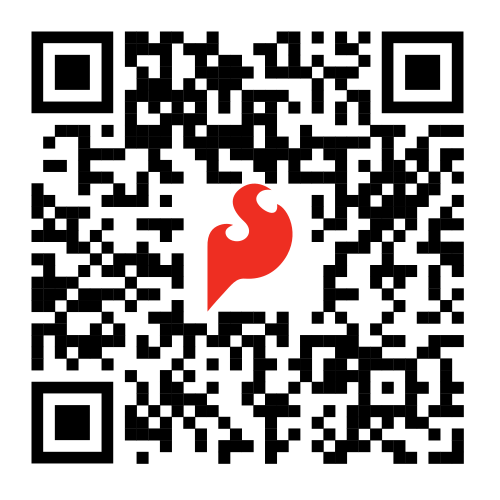
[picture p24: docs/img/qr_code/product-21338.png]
QR code to product page
	[&nbsp;&nbsp;&nbsp;Purchase from SparkFun :fontawesome-solid-cart-plus:{ .heart }](https://www.sparkfun.com/products/21338){ .md-button .md-button--primary }
	</article>

</section>

## :fontawesome-solid-list-check:&nbsp;Required Materials
To get started, users will need a few items. Now some users may already have a few of these items, feel free to modify your cart accordingly.

* [SparkFun Buck Regulator Breakout - 3.3V (AP3429A)](https://www.sparkfun.com/products/21337)
* [Heat Sink](https://www.sparkfun.com/products/18704 "Thermal tape is included") - Used to help dissipate excess heat
    * [Thermal Tape](https://www.sparkfun.com/products/17054) - To attach a heat sink to the board
* [Power Supply](https://www.sparkfun.com/categories/307 "Click here for a full selection of our available power supplies")
* Soldering Tools (1)
{ .annotate }

	1.	Check out the beginner tool kit below; otherwise, click here for a full selection of our available [soldering tools](https://www.sparkfun.com/categories/49).

* [Hookup Wire](https://www.sparkfun.com/categories/141 "Click here for a full selection of our available wires") - May be used to connect the external power or power output
* [Headers](https://www.sparkfun.com/categories/381 "Click here for a full selection of our available headers")  - May be used to connect the external power or power output
* [DC Barrel Jack Adapter](https://www.sparkfun.com/products/119)
* [Small Flathead Screw Driver](https://www.sparkfun.com/categories/376 "Click here for a full selection of our available screwdrivers")

<div class="grid cards col-4" markdown>

-   <a href="https://www.sparkfun.com/products/21337">
	**3.3V Buck Regulator Breakout - (AP3429A)**<br>
	COM-21337

	---

	<figure markdown>
	Product image
	</figure></a>

-   <a href="https://www.sparkfun.com/products/21338">
	**1.8V Buck Regulator Breakout - (AP3429A)**<br>
	COM-21338

	---

	<figure markdown>
	Product image
	</figure></a>

-   <a href="https://www.sparkfun.com/products/18704">
	**Heatsink - 13.20 x 12.10 mm (Copper)**<br>
	PRT-18704

	---

	<figure markdown>
	Product image
	</figure></a>

	!!! tip "Fits both boards"
	!!! info "Thermal tape is included"

-   <a href="https://www.sparkfun.com/products/17054">
	**Thermal Tape 4x4" Square**<br>
	PRT-17054

	---

	<figure markdown>
	Product image
	</figure></a>

-   <a href="https://www.sparkfun.com/products/14681">
	**SparkFun Beginner Tool Kit**<br>
	TOL-14681

	---

	<figure markdown>
	Product image
	</figure></a>

	??? note "New to soldering?"
		Check out our [Through-Hole Soldering Tutorial](https://learn.sparkfun.com/tutorials/5) for a quick introduction!
		<p align="center">
			<a href="https://learn.sparkfun.com/tutorials/5">How to Solder: Through-Hole Soldering<br>
			Tutorial's thumbnail</a>
		</p>

-   <a href="https://www.sparkfun.com/products/11367">
	**Hook-Up Wire - Assortment (Solid Core, 22 AWG)**<br>
	PRT-11367

	---

	<figure markdown>
	Product image
	</figure>
	</a>

-   <a href="https://www.sparkfun.com/products/116">
	**Break Away Headers - Straight**<br>
	PRT-00116

	---

	<figure markdown>
	Product image
	</figure>
	</a>

-   <a href="https://www.sparkfun.com/products/119">
	**DC Barrel Power Jack/Connector**<br>
	PRT-00119

	---

	<figure markdown>
	Product image
	</figure>
	</a>

-   <a href="https://www.sparkfun.com/products/12891">
	**Pocket Screwdriver Set**<br>
	TOL-12891

	---

	<figure markdown>
	Product image
	</figure>
	</a>

</div>

??? note "Jumper Modification"
	!!! tip "New to jumper pads?"
		Check out our [Jumper Pads and PCB Traces Tutorial](https://learn.sparkfun.com/tutorials/664) for a quick introduction!
		<p align="center">
			<a href="https://learn.sparkfun.com/tutorials/664">How to Work with Jumper Pads and PCB Traces<br>
			Tutorial's thumbnail</a>
		</p>

	To modify the [jumper](hardware_overview/#jumper), users will need [soldering equipment](https://www.sparkfun.com/categories/49) and/or a [hobby knife](https://www.sparkfun.com/categories/379).

	<div class="grid cards col-4" markdown>

	-   <a href="https://www.sparkfun.com/products/9325">
		**Solder Lead Free - 100-gram Spool**<br>
		TOL-09325

		---

		<figure markdown>
		Product image
		</figure></a>

	-   <a href="https://www.sparkfun.com/products/14228">**Weller WLC100 Soldering Station**<br>
		TOL-14228

		---
		
		<figure markdown>
		Product image
		</figure></a>

	-   <a href="https://www.sparkfun.com/products/14579">
		**Chip Quik No-Clean Flux Pen - 10mL**<br>
		TOL-14579

		---

		<figure markdown>
		Product image
		</figure></a>

	-   <a href="https://www.sparkfun.com/products/9200">
		**Hobby Knife**<br>
		TOL-09200

		---

		<figure markdown>
		Product image
		</figure>
		</a>
	</div>

??? note "Battery Options"
	If users would like to power their board with a [battery](https://www.sparkfun.com/categories/54), we recommend the following options from our catalog.

	<div class="grid cards col-4" markdown>

	-   <a href="https://www.sparkfun.com/products/15201">
		**Panasonic Alkaline Battery - AA**<br>
		PRT-15201

		---

		<figure markdown>
		Product image
		</figure></a>
	
	-   <a href="https://www.sparkfun.com/products/10891">
		**Battery Holder 3xAA with Cover and Switch - Bare Wire**<br>
		PRT-10891

		---

		<figure markdown>
		Product image
		</figure></a>

	-   <a href="https://www.sparkfun.com/products/14188">
		**Battery Holder 3xAA with Cover and Switch - JST Connector**<br>
		PRT-14188

		---

		<figure markdown>
		Product image
		</figure></a>
	
	-   <a href="https://www.sparkfun.com/products/9749">
		**JST Right-Angle Connector - Through-Hole 2-Pin**<br>
		PRT-09749

		---

		<figure markdown>
		Product image
		</figure></a>
	
	-   <a href="https://www.sparkfun.com/products/9914">
		**JST Jumper 2 Wire Assembly**<br>
		PRT-09914

		---

		<figure markdown>
		Product image
		</figure></a>

	-   <a href="https://www.sparkfun.com/products/13857">
		**Lithium Ion Battery - 400mAh**<br>
		PRT-13857

		---

		<figure markdown>
		Product image
		</figure></a>
	
	-   <a href="https://www.sparkfun.com/products/13854">
		**Lithium Ion Battery - 850mAh**<br>
		PRT-13854

		---

		<figure markdown>
		Product image
		</figure></a>
	
	-   <a href="https://www.sparkfun.com/products/13813">
		**Lithium Ion Battery - 1Ah**<br>
		PRT-13813

		---

		<figure markdown>
		Product image
		</figure></a>
	
	-   <a href="https://www.sparkfun.com/products/13855">
		**Lithium Ion Battery - 2Ah**<br>
		PRT-13855

		---

		<figure markdown>
		Product image
		</figure></a>

	</div>

## :material-bookshelf:&nbsp;Suggested Reading

Below, are a few tutorials that may help users familiarize themselves with various aspects of this product:

<div class="grid cards col-4" markdown align="center">

-   <a href="https://learn.sparkfun.com/tutorials/72">
	**Electric Power**

	---
	
	<figure markdown>
	Tutorial Thumbnail
	</figure></a>

-   <a href="https://learn.sparkfun.com/tutorials/18">
	**Connector Basics**

	---
	
	<figure markdown>
	Tutorial Thumbnail
	</figure></a>

-   <a href="https://learn.sparkfun.com/tutorials/41">
	**Working with Wire**

	---
	
	<figure markdown>
	Tutorial Thumbnail
	</figure></a>

-   <a href="https://learn.sparkfun.com/tutorials/36">
	**How to Power a Project**

	---
	
	<figure markdown>
	Tutorial Thumbnail
	</figure></a>

-   <a href="https://learn.sparkfun.com/tutorials/26">
	**What is a Circuit?**

	---
	
	<figure markdown>
	Tutorial Thumbnail
	</figure></a>

-   <a href="https://learn.sparkfun.com/tutorials/115">
	**Alternating Current (AC) vs. Direct Current (DC)**

	---
	
	<figure markdown>
	Tutorial Thumbnail
	</figure></a>

-   <a href="https://learn.sparkfun.com/tutorials/75">
	**Polarity**

	---
	
	<figure markdown>
	Tutorial Thumbnail
	</figure></a>

-   <a href="https://learn.sparkfun.com/tutorials/62">
	**Logic Levels**

	---
	
	<figure markdown>
	Tutorial Thumbnail
	</figure></a>

-   <a href="https://learn.sparkfun.com/tutorials/1890">
	**Buck Regulator Hookup Guide**

	---

	<figure markdown>
	Tutorial Thumbnail
	</figure></a>

-   <a href="https://docs.sparkfun.com/SparkFun_Buck_Regulator_AP63357DV-7">
	**AP63357 - 5V Buck Regulator Hookup Guide**

	---

	<figure markdown>
	Tutorial Thumbnail
	</figure></a>

-   <a href="https://learn.sparkfun.com/tutorials/5">
	**How to Solder: Through-Hole Soldering**

	---
	
	<figure markdown>
	Tutorial Thumbnail
	</figure></a>

-   <a href="https://learn.sparkfun.com/tutorials/664">
	**How to Work with Jumper Pads and PCB Traces**

	---
	
	<figure markdown>
	Tutorial Thumbnail
	</figure></a>

</div>

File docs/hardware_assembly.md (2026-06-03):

---
icon: material/tools
---

## :material-soldering-iron:&nbsp;Headers

??? note "New to soldering?"
	If you have never soldered before or need a quick refresher, check out our [How to Solder: Through-Hole Soldering](https://learn.sparkfun.com/tutorials/how-to-solder-through-hole-soldering) guide.
	<p align="center">
		<a href="https://learn.sparkfun.com/tutorials/5">How to Solder: Through-Hole Soldering<br>
		Tutorial's thumbnail</a>
	</p>

The pins for the SparkFun AP3429A Buck Regulator Breakout boards are broken out to 0.1"-spaced pins on the outer edges of the board. When selecting headers, be sure you are aware of the functionality and board orientation required.

<figure markdown>
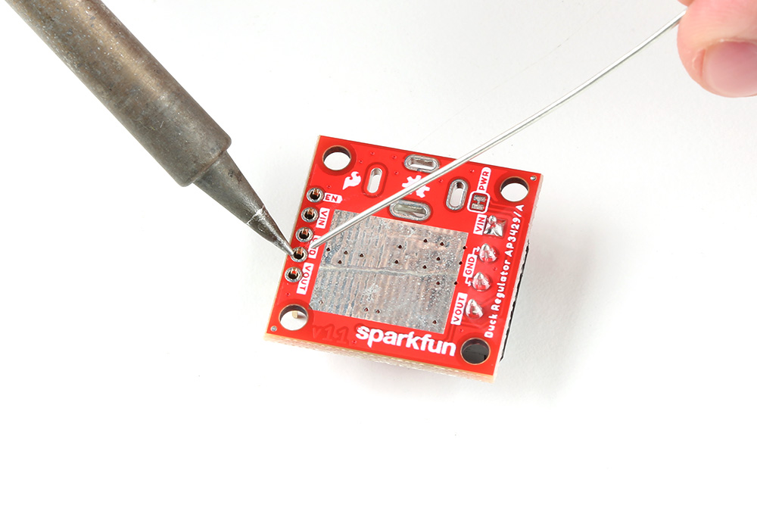
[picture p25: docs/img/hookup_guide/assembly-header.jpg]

<figcaption markdown>
Soldering headers to the AP3429A Buck Regulator Breakout boards.
</figcaption>
</figure>

??? tip "Jumper the Enable Pin"
	On the AP3429A Buck Regulator Breakout board, users can short the [`VIN`](../hardware_overview/#power "Input Voltage") and [`EN`](../hardware_overview/#power-control "Enable Pin") pins. This will allow users to bypass the undervoltage threshold and force the power output to be enabled.

## :material-soldering-iron:&nbsp;Hookup Wire
??? note "New to soldering?"
	If you have never soldered before or need a quick refresher, check out our [How to Solder: Through-Hole Soldering](https://learn.sparkfun.com/tutorials/how-to-solder-through-hole-soldering) guide.
	<p align="center">
		<a href="https://learn.sparkfun.com/tutorials/5">How to Solder: Through-Hole Soldering<br>
		Tutorial's thumbnail</a>
	</p>

Users can also solder their wire connections directly to the pins of the AP3429A Buck Regulator breakout boards. When planning out the connections, be sure you are aware of the functionality required.

!!! danger
	With higher current applications, users should ensure the wires can handle the current load. *(i.e. A 32AWG wire probably won't be able to handle 2A)*

<figure markdown>
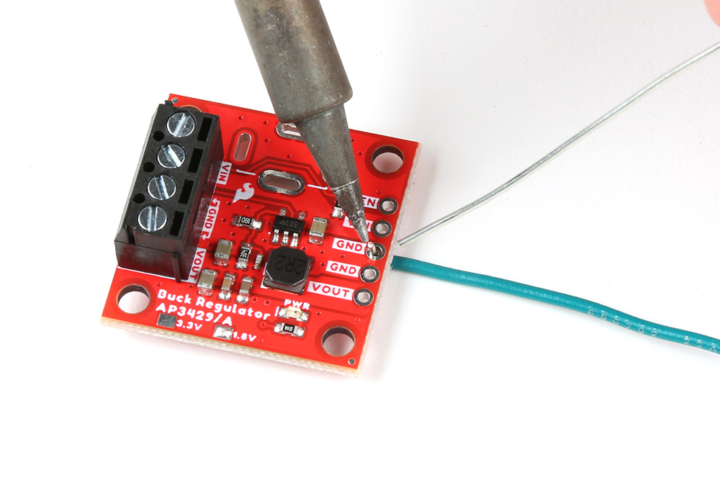
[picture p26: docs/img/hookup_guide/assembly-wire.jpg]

<figcaption markdown>
Soldering wires to the AP3429A Buck Regulator Breakout boards.
</figcaption>
</figure>

## :material-soldering-iron:&nbsp;Barrel Jack PTH
??? note "New to soldering?"
	If you have never soldered before or need a quick refresher, check out our [How to Solder: Through-Hole Soldering](https://learn.sparkfun.com/tutorials/how-to-solder-through-hole-soldering) guide.
	<p align="center">
		<a href="https://learn.sparkfun.com/tutorials/5">How to Solder: Through-Hole Soldering<br>
		Tutorial's thumbnail</a>
	</p>

A [barrel jack connector](https://www.sparkfun.com/products/119) can be added to the AP3429A Buck Regulator breakout boards. The plated through-hole slots allow the barrel jack connector to be oriented on the top or bottom of the board.

<div class="grid cards" markdown>

-   <figure markdown>
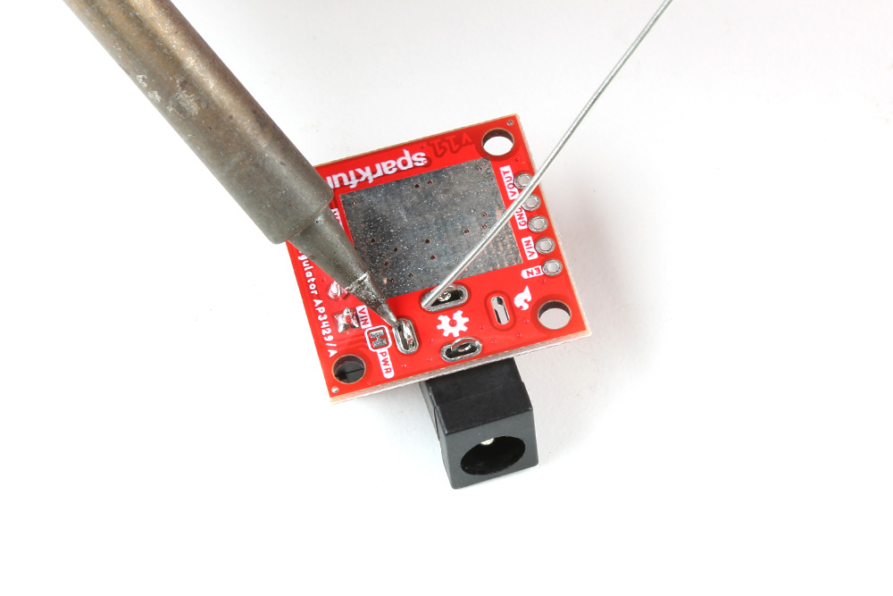
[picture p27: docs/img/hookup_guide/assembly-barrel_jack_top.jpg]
	
	<figcaption markdown>
	Soldering a [barrel jack connector](https://www.sparkfun.com/products/119) onto the top of the AP3429A Buck Regulator Breakout board.
	</figcaption>
	</figure>

-   <figure markdown>
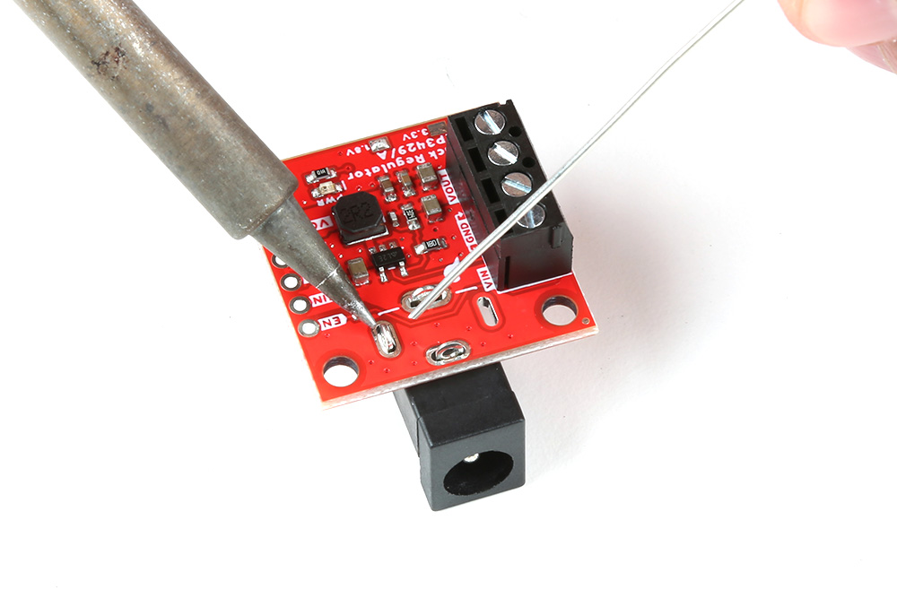
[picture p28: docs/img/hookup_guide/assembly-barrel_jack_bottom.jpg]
	
	<figcaption markdown>
	Soldering a [barrel jack connector](https://www.sparkfun.com/products/119) onto the bottom of the AP3429A Buck Regulator Breakout board.
	</figcaption>
	</figure>

</div>

## :material-screwdriver:&nbsp;Screw Terminals
A screw terminal is a great non-permanent solution, to connect the board. To use the screw terminals, simply insert the correct wires into the screw terminal opening and tighten the screw with a small flathead screwdriver for a firm connection.

<figure markdown>
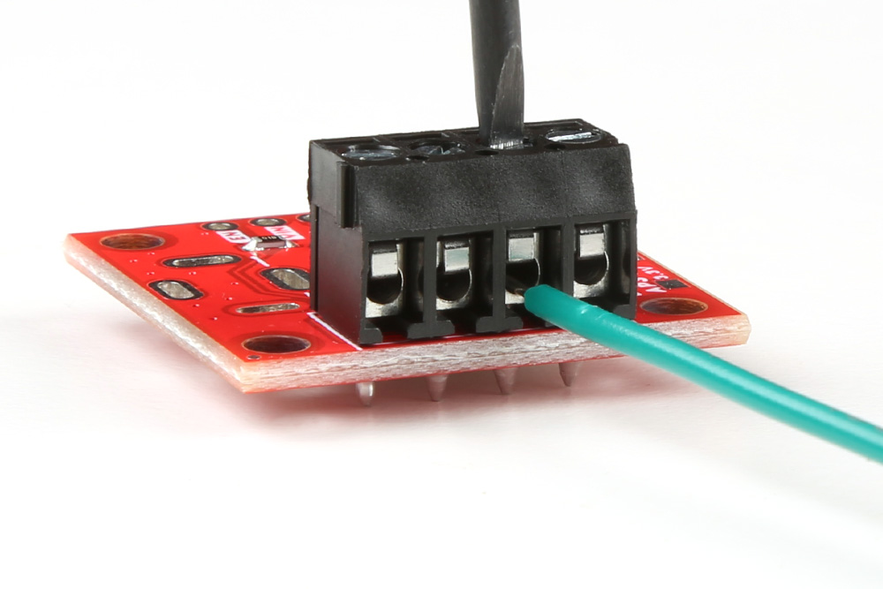
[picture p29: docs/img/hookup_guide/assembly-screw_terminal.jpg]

<figcaption markdown>Connecting a wire to the AP3429A Buck Regulator Breakout Board's' screw terminal.</figcaption>
</figure>

## Battery Power
Unlike our previous buck converter breakouts, the output voltage for these AP3429A buck converters is low enough to be supplied by batteries. Users can connect batteries directly to the board, utilizing the screw terminals or PTH pins.

### :material-soldering-iron:&nbsp;2-Pin JST Connector
Another option is to solder on a [2-pin JST right-angle connector](https://www.sparkfun.com/products/9749). Make sure to note the polarity of the connections to the JST connector before attaching it to the board.

<figure markdown>
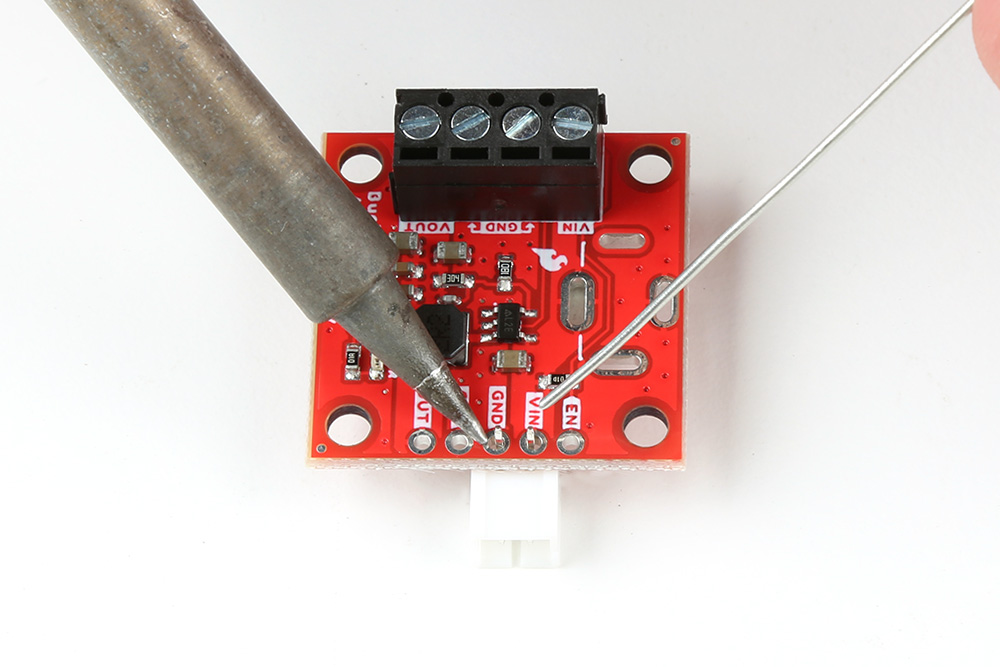
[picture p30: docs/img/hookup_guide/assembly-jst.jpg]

<figcaption markdown>
Soldering a [2-pin JST right-angle connector](https://www.sparkfun.com/products/9749) to the AP3429A Buck Regulator Breakout boards.
</figcaption>
</figure>

This connector is compatible with several of our [LiPo batteries and battery packs](https://www.sparkfun.com/categories/54). Just make sure to select an option that is appropriate for your project.

<div class="grid cards" markdown>

-   <figure markdown>
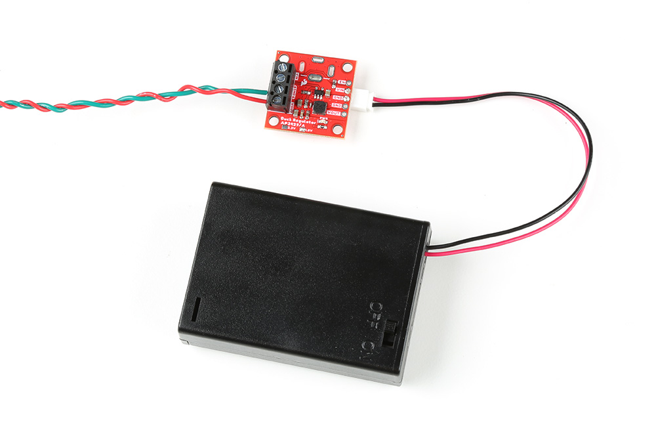
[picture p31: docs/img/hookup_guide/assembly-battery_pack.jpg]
	
	<figcaption markdown>
	The AP3429A Buck Regulator Breakout board powered by a [3xAA battery pack](https://www.sparkfun.com/products/18769).
	</figcaption>
	</figure>

-   <figure markdown>
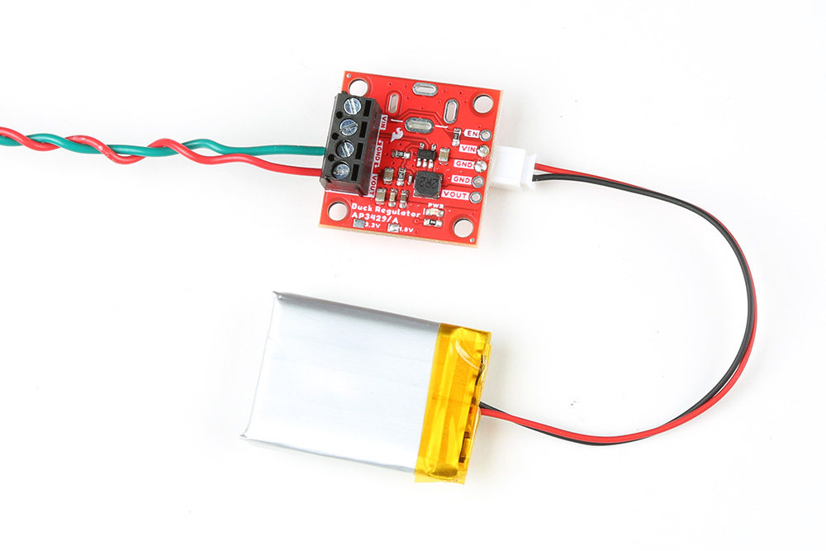
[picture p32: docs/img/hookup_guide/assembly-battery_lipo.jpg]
	
	<figcaption markdown>
	The AP3429A Buck Regulator Breakout board powered by a [400mA LiPo battery](https://www.sparkfun.com/products/13851).
	</figcaption>
	</figure>

	!!! warning "LiPo Batteries"
		Utilize a LiPo battery with an undervoltage protection circuit. This will ensure that the buck regulator boards don't damage the battery as its energy is depleted.

</div>

!!! tip "Disconnecting Hardware"
    <p><b><span style="color:red">DO <u>NOT</u></span></b> remove batteries by pulling on their wires. Instead, it is recommended that pair of dikes (i.e. diagonal wire cutters), pliers, or tweezers be used to pull on the JST connector housing, to avoid damaging the battery wiring.</p>
    <p style="text-align: center;" markdown>
        <a href="https://docs.sparkfun.com/SparkFun_Thing_Plus_ESP32_WROOM_C/img/hookup_guide/assembly_batt_removal.jpg">Disconnect battery w/ dikes Click to enlarge</a>
        <br>
        <i>Using a pair of dikes to disconnect a battery.</i>
    </p>

## Heat Sink
!!! tip
    With larger heat sinks, we recommend a test fit and attaching it last to avoid conflicts with other parts of the board. For example, the heat sink could block the PTH pins/slots or access to the jumper pad.

To attach a [heat sink](https://www.sparkfun.com/products/18704) to the board, users will also need a piece of [thermal tape](https://www.sparkfun.com/products/17054). We recommend the following procedure:

1. Cut out a piece of [thermal tape](https://www.sparkfun.com/products/17054) to fit the bottom of the [heat sink](https://www.sparkfun.com/products/18704).
	
	!!! tip
		Covering the entire bottom of the heat sink can insulate the electrical contacts on the board from shorting.

    * For a perfect fit, users can place the heat sink over the tape and trace the outline to cut with scissors.
    * For a perfect fit, users can also place the heat sink over the tape and cut the outline with a [hobby knife](https://www.sparkfun.com/products/9200).

2. Place the piece of thermal tape on the bottom of the heat sink.

	!!! tip
		We recommend peeling off just one side of the backing sheet or [release liner](https://en.wikipedia.org/wiki/Release_liner) to place the thermal tape on the heat sink. Users can then peel the other side off when they are ready to place the heat sink on their board.
	
3. Attach the heat sink to the board.
    * Make sure to make any jumper modifications and/or solder any connections before placing the heat sink on the board.
    * Make sure to avoid any electrical contact with the sides of the heat sink.

<div class="grid cards" markdown>

-   <figure markdown>
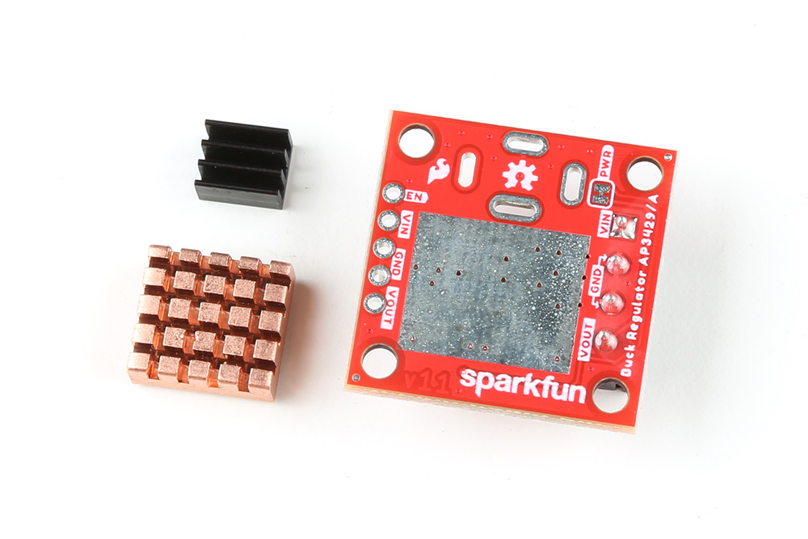
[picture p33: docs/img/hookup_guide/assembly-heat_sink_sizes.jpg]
	
	<figcaption markdown>
	Different [heat sinks](https://www.sparkfun.com/categories/tags/heatsink) next to the AP3429A Buck Regulator Breakout board.
	</figcaption>
	</figure>

-   <figure markdown>
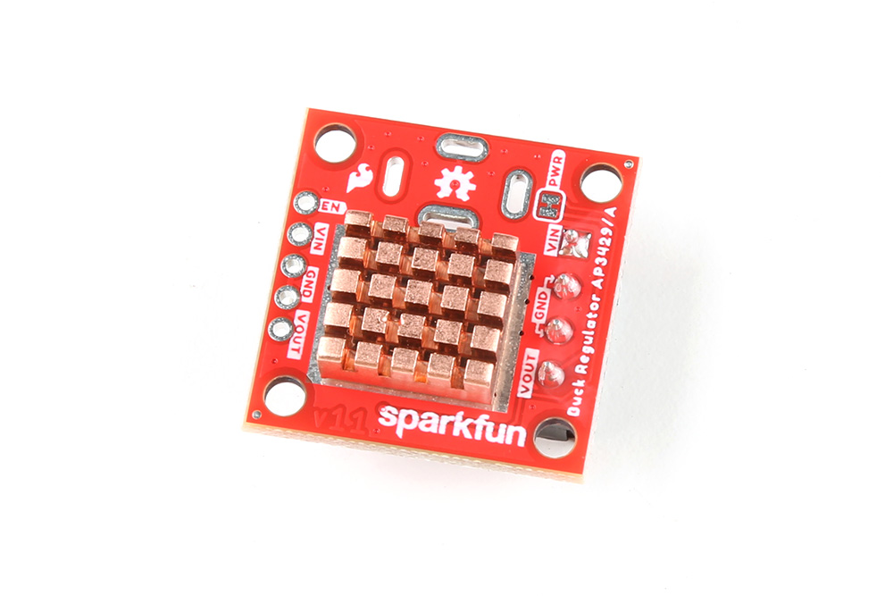
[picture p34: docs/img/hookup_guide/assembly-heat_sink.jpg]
	
	<figcaption markdown>
	[Heat sink](https://www.sparkfun.com/products/18704) attached to the AP3429A Buck Regulator Breakout board.
	</figcaption>
	</figure>

</div>

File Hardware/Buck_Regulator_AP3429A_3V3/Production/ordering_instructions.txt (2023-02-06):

panel size, 221x169mm
PCB thickness, 1.6mm
number of layers, 2
soldermask color, Red
silkscreen color, White
oz copper, 1oz
finish, HASL lead free
stencils, top
pcs per panel, 48
min trace width, 0.2032mm / 0.0080in
min drill size, 0.3500mm / 0.0138in

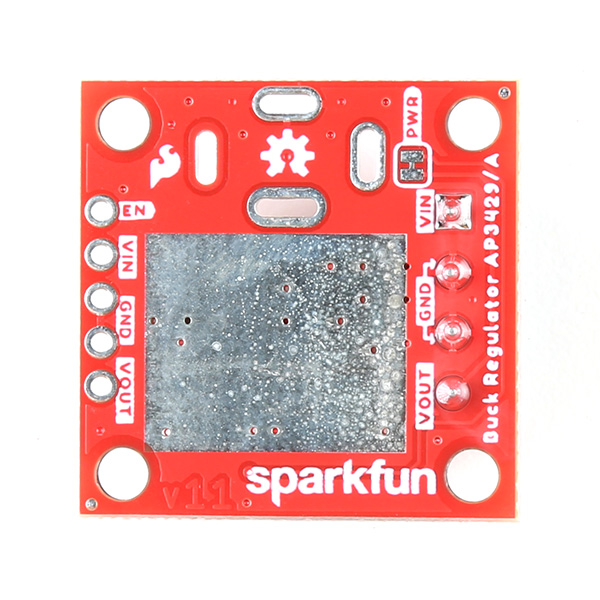
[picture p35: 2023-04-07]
docs/img/hookup_guide/3V3-bottom.jpg

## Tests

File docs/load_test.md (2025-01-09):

---
icon: material/speedometer
---

For users who would like to test their buck regulators, this page demonstrates a simple load test.

!!! note
	Users who wish to test the maximum parameters of their board should consider using a professional/benchtop DC electric load tester, instead of the [variable load kit](https://www.sparkfun.com/products/14449). 

## Required Hardware
To test the buck regulator boards, users will need the following hardware:

* DC Electric Load Tester
	* We are using the [SparkFun Variable Load Kit](https://www.sparkfun.com/products/14449)
* Power Supply
    * Use a benchtop-style power supply where you can configure the output voltage and see the current draw when loaded.
	* We are using the [80W DC Power Supply](https://www.sparkfun.com/products/retired/9291) *(retired product)*

<div class="grid cards" markdown>

-   <a href="https://www.sparkfun.com/products/retired/9291">**Power Supply - 80W DC Switching Mode**<br>
	TOL-09291

	---

	<figure markdown>
	
	</figure></a>

-   <a href="https://www.sparkfun.com/products/14449">**SparkFun Variable Load Kit**<br>
	KIT-14449

	---

	<figure markdown>
	
	</figure>
	</a>

</div>

## Hardware Setup
For this test, the hardware was setup up as follows:

* Power was supplied to the buck regulator through the soldered barrel jack.
* The output power from the buck regulator was connected to the variable load kit, through the screw terminal.
* No heat sink was attached to the buck regulator.

<figure markdown>
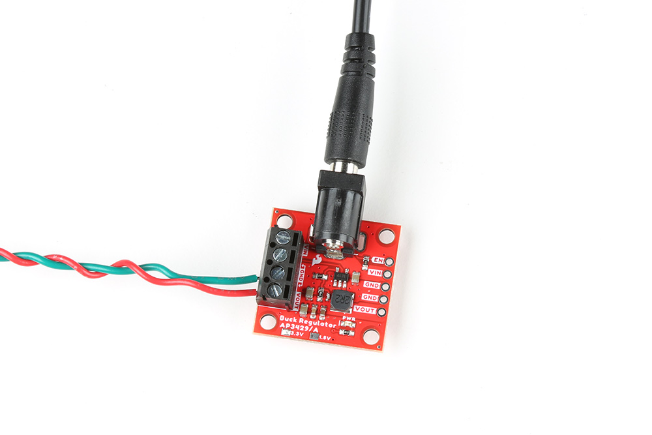
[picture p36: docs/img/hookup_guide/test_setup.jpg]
<br>
<figcaption markdown>Setup for a basic load test on the AP3429A Buck Regulator Breakout boards.</figcaption>
</figure>

## Test
To perform the test, the power supply was set to provide 4.5V at up to 4A. Meanwhile, the SparkFun variable load kit was configured to draw 0.5A.

<figure markdown>
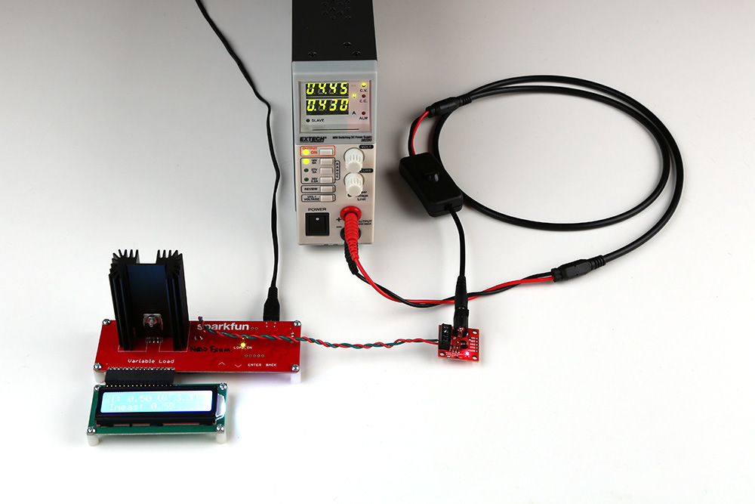
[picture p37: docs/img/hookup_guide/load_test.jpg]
<br>
<figcaption markdown>A load test being performed on the AP3429A Buck Regulator Breakout board.</figcaption>
</figure>

Although it is a little hard to see in the picture, the power supply is providing 4.45V with a 430mA current draw to the buck regulator. The variable load kit is drawing 0.49A with the 3.34V output voltage from the buck regulator.

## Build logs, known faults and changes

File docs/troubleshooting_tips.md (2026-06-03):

---
icon: sfe-logo
---

!!! warning "Need Help?"
    If you need technical assistance or more information on a product that is not working as you expected, we recommend heading on over to the [SparkFun Technical Assistance](https://www.sparkfun.com/technical_assistanc) page for some initial troubleshooting.

    <article style="text-align: center;" markdown>
    [SparkFun Technical Assistance Page](https://www.sparkfun.com/technical_assistance){ .md-button .md-button--primary }
    </article>
    
    If you can't find what you need there, the [SparkFun Forums](https://forum.sparkfun.com/index.php) is a great place to search product forums and ask questions.
    
    !!! info "Account Registration Required"
        If this is your first visit to our forum, you'll need to create a [Forum Account](https://forum.sparkfun.com/ucp.php?mode=register) to post questions.

## Bypass the UVLO
!!! info "Default Configuration"
    On our boards, the `EN` pin is pulled-up to enable the power output from the board by default.

On the Buck Regulator boards, users can short/[jumper](https://www.sparkfun.com/products/9044) the [`VIN`](../hardware_overview/#power "Input Voltage") and [`EN`](../hardware_overview/#power-control "Enable Pin") pins. This will bypass the undervoltage lockout setting and allow users to provide a lower input voltage. However, it should be noted that because this is a step-down converter and the input voltage should remain higher than the regulated output voltage.

## Connecting Batteries
For lower current applications, users can connect a battery as the power source. However, please be aware of the input voltage range for each board and the limitations of utilizing rechargeable batteries. We recommend a 3xAA battery pack and AA alkaline batteries for novice users to avoid technical complications.

<div class="grid cards" markdown>

-   <a href="https://www.sparkfun.com/products/10891">**Battery Holder 3xAA with Cover and Switch - Bare Wire**<br>
	PRT-10891

	---

	<figure markdown>
	
	</figure></a>

-   <a href="https://www.sparkfun.com/products/15201">**Panasonic Alkaline Battery - AA**<br>
	PRT-15201

	---

	<figure markdown>
	
	</figure>
	</a>

</div>

!!! tip " Lithium Ion Batteries"
    While lithium polymer batteries have a nominal voltage of 3.7V, the voltage will vary as it is discharged. These types of batteries often have a range of approximately **3.2V** to **4.2V** and will be damaged if their voltage exceeds these parameters. Therefore, we recommend that users only connect LiPo batteries with a protection circuit from the manufacturer.

    !!! warning
        For example, the [18650 lithium-ion batteries](https://www.sparkfun.com/products/12895) in our catalog don't include a battery protection circuit. If used with the 1.8V buck regulator and left to discharge below 3.2V, the battery would be permanently damaged and rendered useless.
        
        There is no way to recover the battery from this type of damage. *(While there are hacks to get the battery working again, its performance will be significantly reduced.)*

    !!! info
        With an undervoltage threshold of 3.7V, [3.3V buck regulator](https://www.sparkfun.com/products/21337) will not be able to utilize the full capacity of a LiPo battery. The board will be unable to access the last 40-50% of the LiPo battery's charge capacity.

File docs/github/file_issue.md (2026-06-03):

# Did we make a mistake?

Spot something wrong? Please let us know. 

<!-- Technical Assistance Box -->
!!! warning "Need Help?"
    If you need technical assistance or more information on a product that is not working as you expected, we recommend heading on over to the [SparkFun Technical Assistance](https://www.sparkfun.com/technical_assistance) page for some initial troubleshooting. This **Submit Issues** page is not where users should seek assistance.

    <article style="text-align: center;" markdown>
    [SparkFun Technical Assistance Page](https://www.sparkfun.com/technical_assistance){ .md-button .md-button--primary }
    </article>
    
    If you can't find what you need there, the [SparkFun Forums](https://forum.sparkfun.com/index.php) is a great place to search the product forums and ask questions.
    
    !!! info "Account Registration Required"
        For your first visit to our forum, you'll need to create a [Forum Account](https://forum.sparkfun.com/ucp.php?mode=register) to post questions.

## Discrepancies in the Documentation

All of our documentation can be modified by you! Please help us make it better.

* The documentation files for these pages are contained in the [`docs` folder](https://github.com/sparkfun/SparkFun_Buck_Regulator_AP3429A/tree/main/docs) of the [SparkFun AP3429A Buck Regulator repository](https://github.com/sparkfun/SparkFun_Buck_Regulator_AP3429A).

### 🔍 Spot something wrong?

If a section of the documentation is incorrect, please [open an issue](https://github.com/sparkfun/SparkFun_Buck_Regulator_AP3429A/issues) and let us know.

### Do you have a suggested correction?

1. With a GitHub account, [fork this repository](https://github.com/sparkfun/SparkFun_Buck_Regulator_AP3429A/fork).
2. Add your correction(s) or improvement(s) to the markdown file(s)
3. File a pull request with your changes, and enjoy making the ~~words~~ ~~worlds~~ world a better place.
	* Once received, the documentation specialist will automatically be notified.
	* We will review your suggested improvement(s) to make sure they are correct and fit within our documentation standards.

## Problems in the Hardware Design

All of our designs are open-source! Please help us make it better.

* Our board design files are contained in the [`Hardware` folder](https://github.com/sparkfun/SparkFun_Buck_Regulator_AP3429A/tree/main/Hardware) of the [SparkFun AP3429A Buck Regulator repository](https://github.com/sparkfun/SparkFun_Buck_Regulator_AP3429A).

### Does something not make sense? 🤔

If part of the design is confusing, please [open an issue](https://github.com/sparkfun/SparkFun_Buck_Regulator_AP3429A/issues) and let us know.

### Did we forget to include an important function of the board? 🤦

If part of the board's functionality is missing, please [open an issue](https://github.com/sparkfun/SparkFun_Buck_Regulator_AP3429A/issues) and file a feature request.

!!! tip "Design Considerations"
	Please keep in mind that we may intentionally exclude certain functions of the board to meet our product design requirements.
	
	* *For example, our Qwiic Micro boards are intended to fit on a small board layout and only use I<sup>2</sup>C communication; therefore, we may not have the SPI and interrupt pins available for users.*

### Do you wish to contribute directly to improving the board design?

1. With a GitHub account, [fork this repository](https://github.com/sparkfun/SparkFun_Buck_Regulator_AP3429A/fork).
2. Add your design augmentation(s)
3. File a pull request with your changes, and enjoy making the ~~words~~ ~~worlds~~ world a better place.
	1. Once received, the engineer in charge of the original design will automatically be notified.
	2. We will review your suggested improvement(s) to verify that they are within our board design standards and meet our product design requirements.
	3. If approved, we will flag these changes for our next board revision. Congrats! 🍻

		!!! info
			Even if your suggestion is accepted, these changes may not be immediately available for purchase. We may have to cycle through our current product inventory first.

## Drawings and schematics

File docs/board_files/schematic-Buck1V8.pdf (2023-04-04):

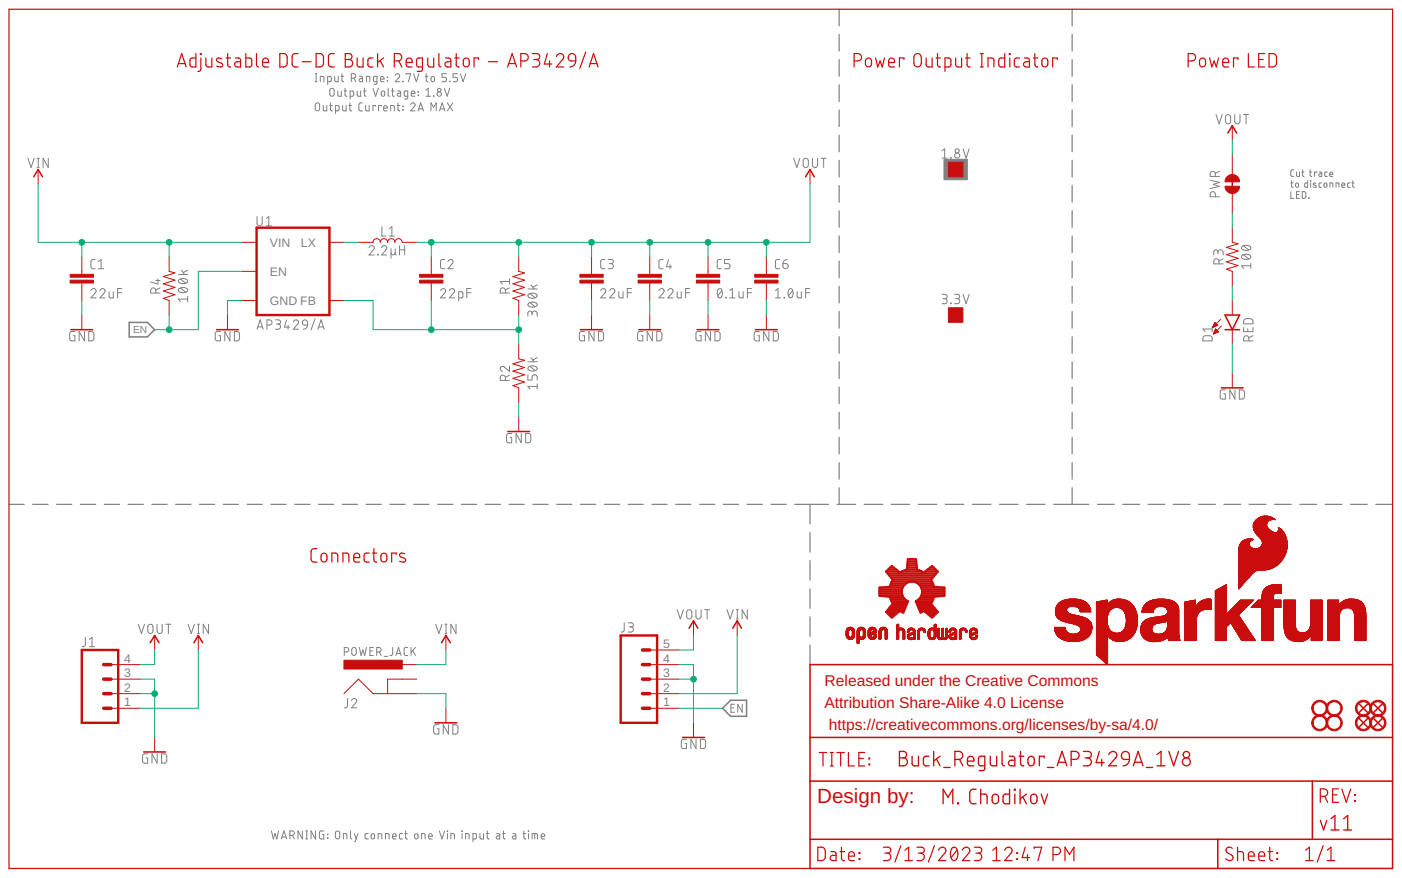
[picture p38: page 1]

Released under the Creative Commons
Attribution Share-Alike 4.0 License
https://creativecommons.org/licenses/by-sa/4.0/

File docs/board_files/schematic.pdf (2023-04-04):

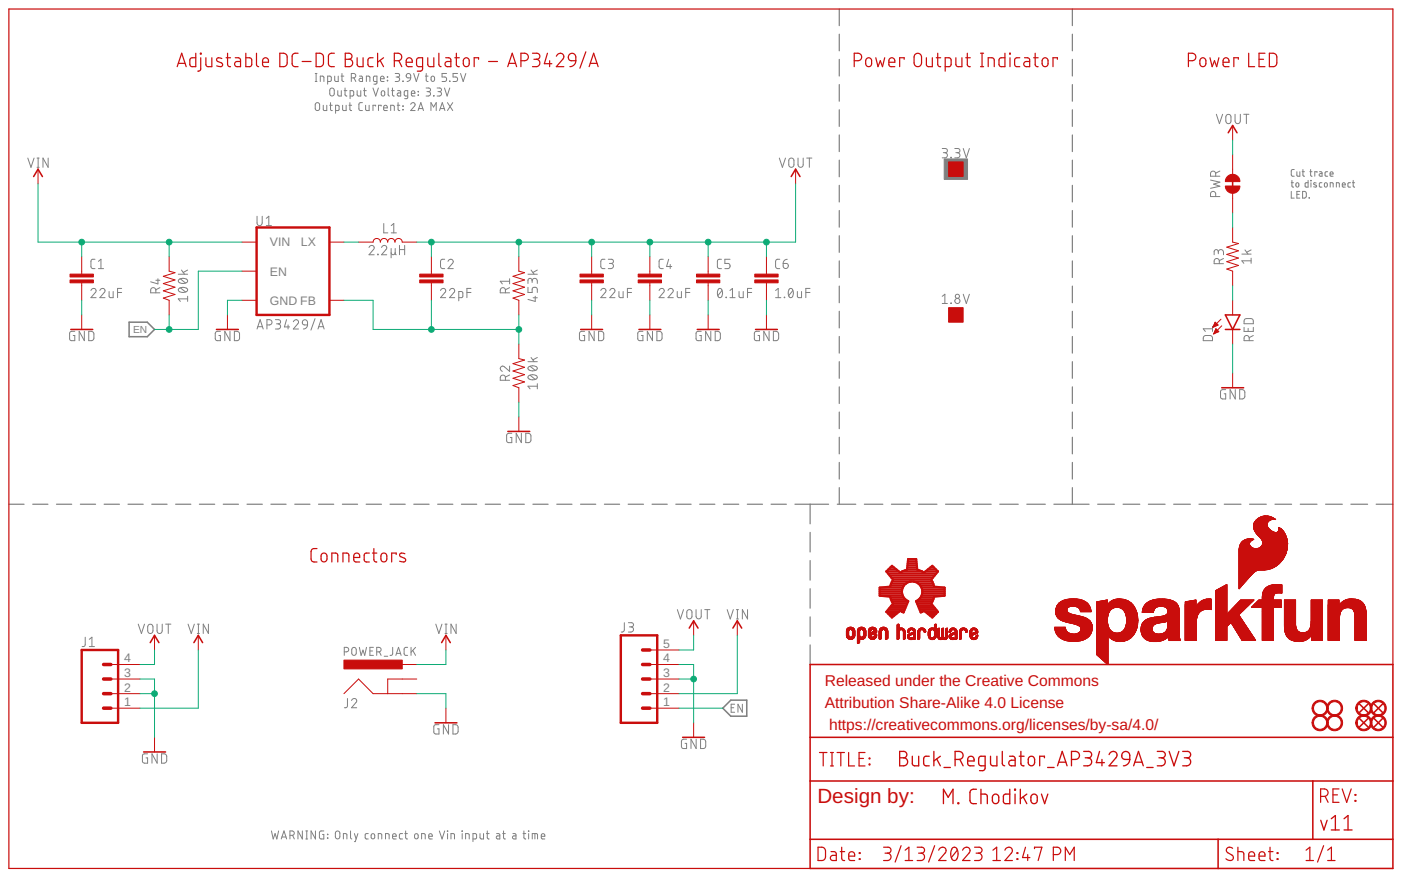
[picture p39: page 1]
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

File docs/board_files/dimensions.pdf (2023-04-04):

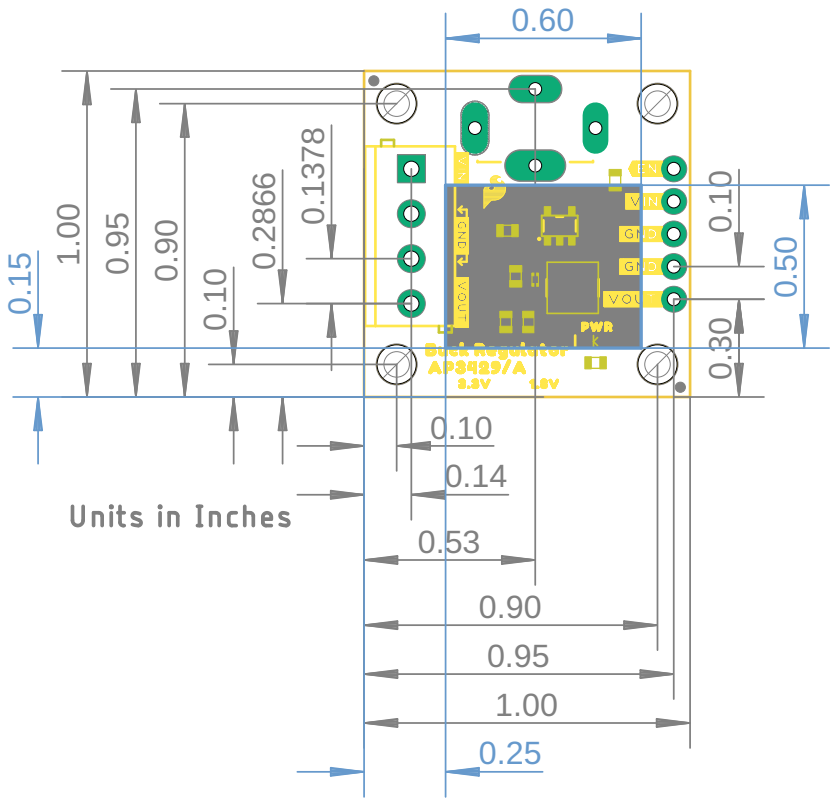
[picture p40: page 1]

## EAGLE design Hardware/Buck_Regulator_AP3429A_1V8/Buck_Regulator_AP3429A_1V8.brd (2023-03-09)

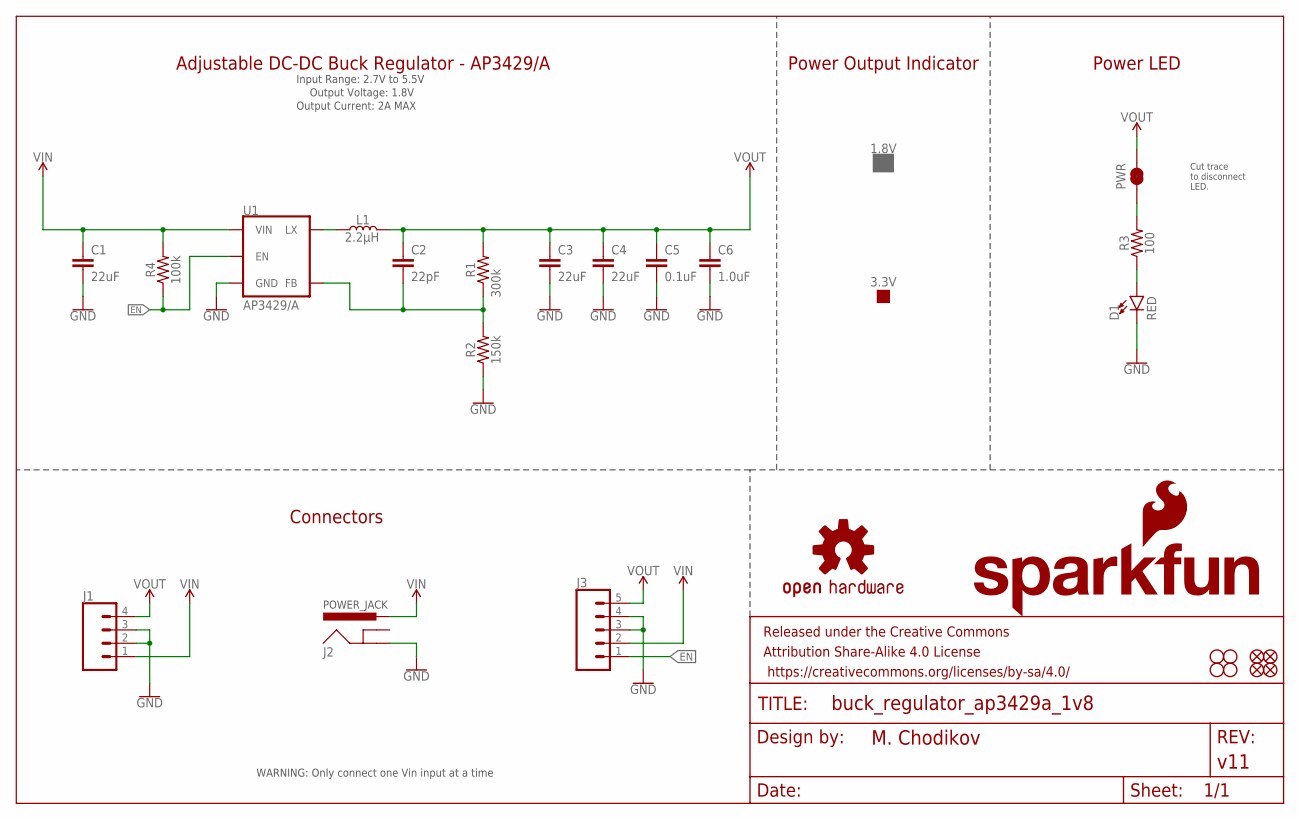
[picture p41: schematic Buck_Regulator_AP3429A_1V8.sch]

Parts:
1.8V: PROD_ID_PASTE_NO-SILK; PRODUCT_IDENT_PASTE_NO-SILK
3.3V: PROD_ID_NO-PASTE_NO_SILK; PRODUCT_IDENT_NO_NO-SILK
C1, C3, C4: 22uF; 0805
C2: 22pF; 0402-TIGHT
C5: 0.1uF; 0603
C6: 1.0uF; 0603
D1: RED; LED-0603
FD1, FD2, FD3, FD4: FIDUCIALUFIDUCIAL; FIDUCIAL-MICRO
FRAME1: FRAME-LEDGER; CREATIVE_COMMONS
H1, H2, H3, H4: STAND-OFFTIGHT; STAND-OFF-TIGHT
J1: Screw Terminal; SCREWTERMINAL-3.5MM-4
J2: POWER_JACKPOWER_JACK_SLOT_COMBO; POWER_JACK_PTH_SLOT_BOTH
J3: Breakout Headers; 1X05_NO_SILK
L1: 2.2μH; INDUCTOR_4X4MM
LOGO1: OSHW-LOGOS; OSHW-LOGO-S
LOGO2: SFE_LOGO_NAME.1_INCH; SFE_LOGO_NAME_.1
LOGO3: SFE_LOGO_FLAME.1_INCH; SFE_LOGO_FLAME_.1
PWR: JUMPER-SMT_2_NC_TRACE_SILK; SMT-JUMPER_2_NC_TRACE_SILK
R1: 300k; 0603
R2: 150k; 0603
R3: 100; 0603
R4: 100k; 0603
U1: AP3429/A; SOT23-5

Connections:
EN: J3.1, R4.1, U1.1 (EN)
GND: C1.2, C3.2, C4.2, C5.2, C6.2, D1.C, J1.2, J1.3, J2.GND, J3.3, J3.4, R2.1, U1.2 (GND)
unnamed: L1.P$1 (1), U1.3 (LX)
unnamed: C2.2, R1.1, R2.2, U1.5 (FB)
unnamed: PWR.1, R3.2
unnamed: D1.A, R3.1
VIN: C1.1, J1.1, J2.PWR, J3.2, R4.2, U1.4 (VIN)
VOUT: C2.1, C3.1, C4.1, C5.1, C6.1, J1.4, J3.5, L1.P$2 (2), PWR.2, R1.2

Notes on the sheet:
Input Range: 2.7V to 5.5V
Adjustable DC-DC Buck Regulator - AP3429/A
Power LED
Connectors
POWER_JACK
Output Current: 2A MAX
WARNING: Only connect one Vin input at a time
Power Output Indicator
Cut trace to disconnect LED.
Output Voltage: 1.8V

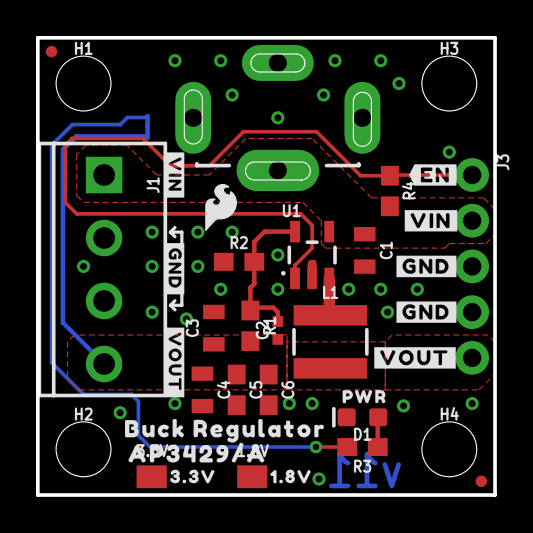
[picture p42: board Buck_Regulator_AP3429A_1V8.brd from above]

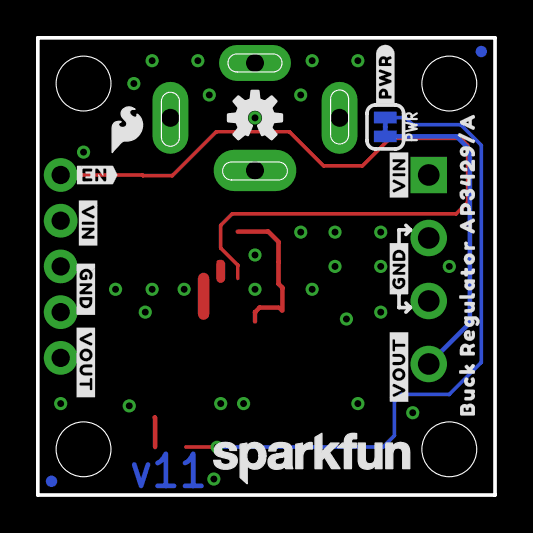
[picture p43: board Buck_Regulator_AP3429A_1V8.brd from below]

Board: 2 copper layers, 25.4 x 25.4 mm, 55 parts (15 on the bottom side), 8 nets.

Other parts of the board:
U$1: SFE_LOGO_FLAME_.1
U$2: BUCK_REGULATOR24
U$3: AP3429#A25
U$4: #VOUT#3431
U$5, U$6: #GND#3432
U$7: #VIN#3433
U$8, U$10: #GND#3446
U$9, U$15: #VIN#3445
U$11, U$13: #VOUT#3447
U$12: #EN#3448
U$14: #PWR#3451
U$16: BUCK_REGULATOR_AP3429#A3453
U$17: ORDERING_INSTRUCTIONS
U$19: 1#8V3441
U$20: PWR3441
U$21: #VOUT#3437
U$22: #VIN#3438
U$23: 3#3V3441
U$24: #GND#3439
U$25: #EN#3443

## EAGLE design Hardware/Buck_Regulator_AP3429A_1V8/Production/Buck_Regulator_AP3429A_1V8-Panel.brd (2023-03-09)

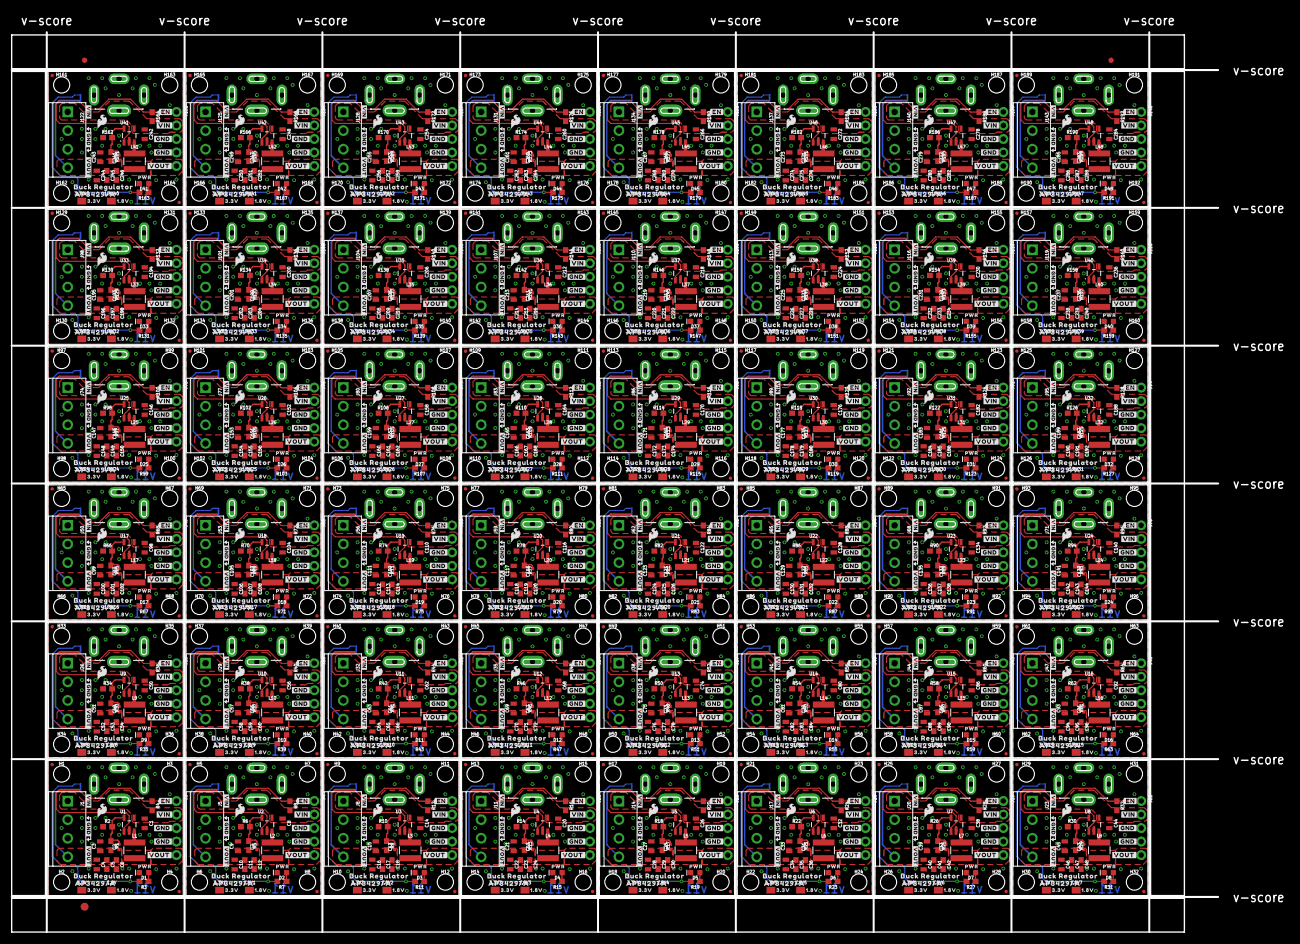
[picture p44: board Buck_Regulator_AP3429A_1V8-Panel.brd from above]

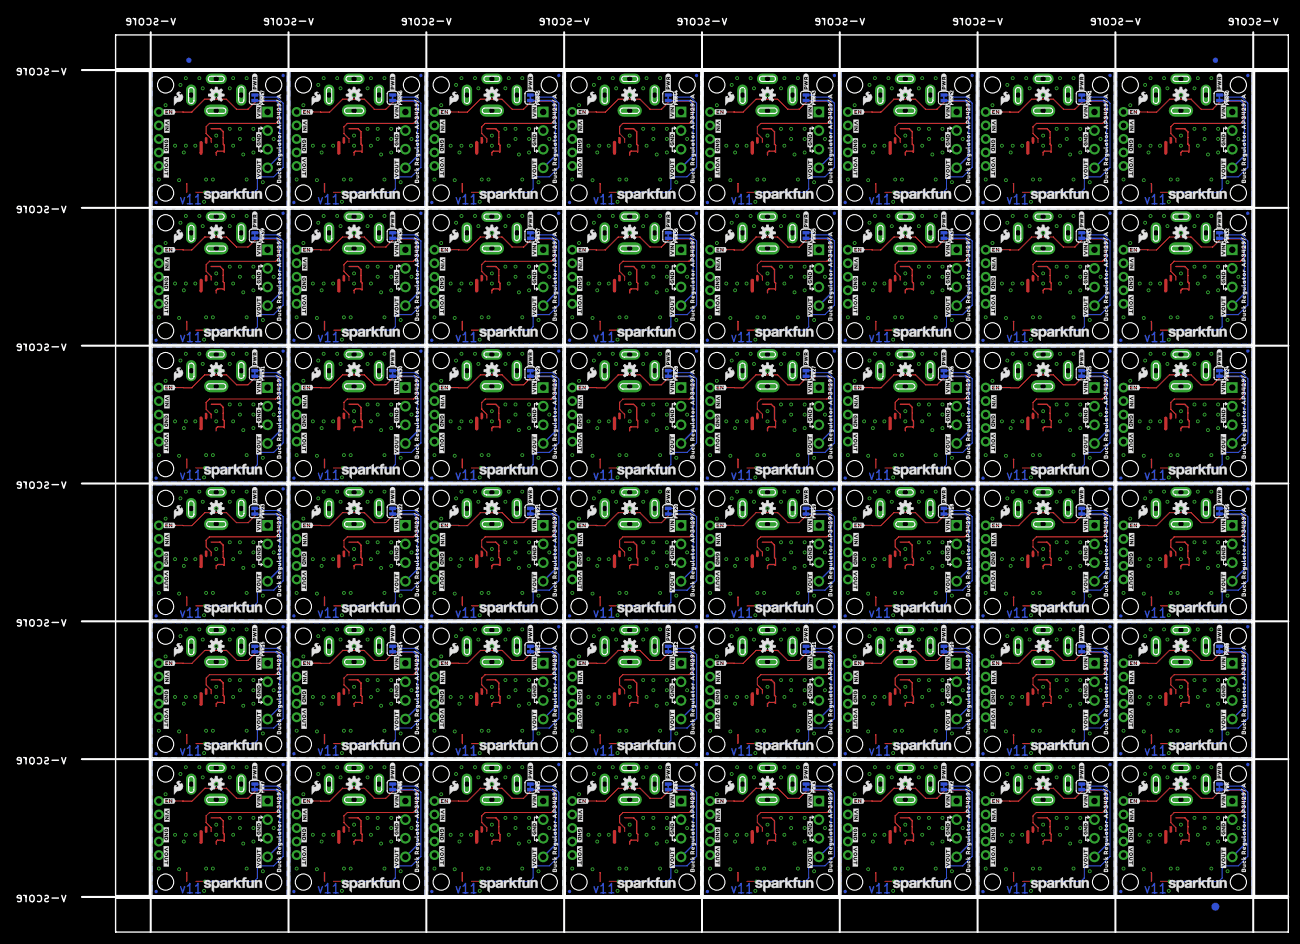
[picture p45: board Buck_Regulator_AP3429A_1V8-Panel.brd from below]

Board: 2 copper layers, 226.8 x 169.2 mm, 2550 parts (723 on the bottom side), 384 nets.

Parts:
1.8V, 1.8V1, 1.8V2, 1.8V3, 1.8V4, 1.8V5, 1.8V6, 1.8V7, 1.8V8, 1.8V9, 1.8V10, 1.8V11, 1.8V12, 1.8V13, 1.8V14, 1.8V15, 1.8V16, 1.8V17, 1.8V18, 1.8V19, 1.8V20, 1.8V21, 1.8V22, 1.8V23, 1.8V24, 1.8V25, 1.8V26, 1.8V27, 1.8V28, 1.8V29, 1.8V30, 1.8V31, 1.8V32, 1.8V33, 1.8V34, 1.8V35, 1.8V36, 1.8V37, 1.8V38, 1.8V39, 1.8V40, 1.8V41, 1.8V42, 1.8V43, 1.8V44, 1.8V45, 1.8V46, 1.8V47: PROD_ID_PASTE_NO-SILK; PRODUCT_IDENT_PASTE_NO-SILK
3.3V, 3.3V1, 3.3V2, 3.3V3, 3.3V4, 3.3V5, 3.3V6, 3.3V7, 3.3V8, 3.3V9, 3.3V10, 3.3V11, 3.3V12, 3.3V13, 3.3V14, 3.3V15, 3.3V16, 3.3V17, 3.3V18, 3.3V19, 3.3V20, 3.3V21, 3.3V22, 3.3V23, 3.3V24, 3.3V25, 3.3V26, 3.3V27, 3.3V28, 3.3V29, 3.3V30, 3.3V31, 3.3V32, 3.3V33, 3.3V34, 3.3V35, 3.3V36, 3.3V37, 3.3V38, 3.3V39, 3.3V40, 3.3V41, 3.3V42, 3.3V43, 3.3V44, 3.3V45, 3.3V46, 3.3V47: PROD_ID_NO-PASTE_NO_SILK; PRODUCT_IDENT_NO_NO-SILK
C1, C3, C4, C8, C9, C10, C14, C15, C16, C20, C21, C22, C26, C27, C28, C32, C33, C34, C38, C39, C40, C44, C45, C46, C50, C51, C52, C56, C57, C58, C62, C63, C64, C68, C69, C70, C74, C75, C76, C80, C81, C82, C86, C87, C88, C92, C93, C94, C98, C99, C100, C104, C105, C106, C110, C111, C112, C116, C117, C118, C122, C123, C124, C128, C129, C130, C134, C135, C136, C140, C141, C142, C146, C147, C148, C152, C153, C154, C158, C159, C160, C164, C165, C166, C170, C171, C172, C176, C177, C178, C182, C183, C184, C188, C189, C190, C194, C195, C196, C200, C201, C202, C206, C207, C208, C212, C213, C214, C218, C219, C220, C224, C225, C226, C230, C231, C232, C236, C237, C238, C242, C243, C244, C248, C249, C250, C254, C255, C256, C260, C261, C262, C266, C267, C268, C272, C273, C274, C278, C279, C280, C284, C285, C286: 22uF; 0805
C2, C7, C13, C19, C25, C31, C37, C43, C49, C55, C61, C67, C73, C79, C85, C91, C97, C103, C109, C115, C121, C127, C133, C139, C145, C151, C157, C163, C169, C175, C181, C187, C193, C199, C205, C211, C217, C223, C229, C235, C241, C247, C253, C259, C265, C271, C277, C283: 22pF; 0402-TIGHT
C5, C11, C17, C23, C29, C35, C41, C47, C53, C59, C65, C71, C77, C83, C89, C95, C101, C107, C113, C119, C125, C131, C137, C143, C149, C155, C161, C167, C173, C179, C185, C191, C197, C203, C209, C215, C221, C227, C233, C239, C245, C251, C257, C263, C269, C275, C281, C287: 0.1uF; 0603
C6, C12, C18, C24, C30, C36, C42, C48, C54, C60, C66, C72, C78, C84, C90, C96, C102, C108, C114, C120, C126, C132, C138, C144, C150, C156, C162, C168, C174, C180, C186, C192, C198, C204, C210, C216, C222, C228, C234, C240, C246, C252, C258, C264, C270, C276, C282, C288: 1.0uF; 0603
D1, D2, D3, D4, D5, D6, D7, D8, D9, D10, D11, D12, D13, D14, D15, D16, D17, D18, D19, D20, D21, D22, D23, D24, D25, D26, D27, D28, D29, D30, D31, D32, D33, D34, D35, D36, D37, D38, D39, D40, D41, D42, D43, D44, D45, D46, D47, D48: RED; LED-0603
E$1, E$2, E$3, E$4: FIDUCIAL-1X2
E$5, E$6: FIDUCIAL-1.5X3
FD1, FD2, FD3, FD4, FD5, FD6, FD7, FD8, FD9, FD10, FD11, FD12, FD13, FD14, FD15, FD16, FD17, FD18, FD19, FD20, FD21, FD22, FD23, FD24, FD25, FD26, FD27, FD28, FD29, FD30, FD31, FD32, FD33, FD34, FD35, FD36, FD37, FD38, FD39, FD40, FD41, FD42, FD43, FD44, FD45, FD46, FD47, FD48, FD49, FD50, FD51, FD52, FD53, FD54, FD55, FD56, FD57, FD58, FD59, FD60, FD61, FD62, FD63, FD64, FD65, FD66, FD67, FD68, FD69, FD70, FD71, FD72, FD73, FD74, FD75, FD76, FD77, FD78, FD79, FD80, FD81, FD82, FD83, FD84, FD85, FD86, FD87, FD88, FD89, FD90, FD91, FD92, FD93, FD94, FD95, FD96, FD97, FD98, FD99, FD100, FD101, FD102, FD103, FD104, FD105, FD106, FD107, FD108, FD109, FD110, FD111, FD112, FD113, FD114, FD115, FD116, FD117, FD118, FD119, FD120, FD121, FD122, FD123, FD124, FD125, FD126, FD127, FD128, FD129, FD130, FD131, FD132, FD133, FD134, FD135, FD136, FD137, FD138, FD139, FD140, FD141, FD142, FD143, FD144, FD145, FD146, FD147, FD148, FD149, FD150, FD151, FD152, FD153, FD154, FD155, FD156, FD157, FD158, FD159, FD160, FD161, FD162, FD163, FD164, FD165, FD166, FD167, FD168, FD169, FD170, FD171, FD172, FD173, FD174, FD175, FD176, FD177, FD178, FD179, FD180, FD181, FD182, FD183, FD184, FD185, FD186, FD187, FD188, FD189, FD190, FD191, FD192: FIDUCIALUFIDUCIAL; FIDUCIAL-MICRO
H1, H2, H3, H4, H5, H6, H7, H8, H9, H10, H11, H12, H13, H14, H15, H16, H17, H18, H19, H20, H21, H22, H23, H24, H25, H26, H27, H28, H29, H30, H31, H32, H33, H34, H35, H36, H37, H38, H39, H40, H41, H42, H43, H44, H45, H46, H47, H48, H49, H50, H51, H52, H53, H54, H55, H56, H57, H58, H59, H60, H61, H62, H63, H64, H65, H66, H67, H68, H69, H70, H71, H72, H73, H74, H75, H76, H77, H78, H79, H80, H81, H82, H83, H84, H85, H86, H87, H88, H89, H90, H91, H92, H93, H94, H95, H96, H97, H98, H99, H100, H101, H102, H103, H104, H105, H106, H107, H108, H109, H110, H111, H112, H113, H114, H115, H116, H117, H118, H119, H120, H121, H122, H123, H124, H125, H126, H127, H128, H129, H130, H131, H132, H133, H134, H135, H136, H137, H138, H139, H140, H141, H142, H143, H144, H145, H146, H147, H148, H149, H150, H151, H152, H153, H154, H155, H156, H157, H158, H159, H160, H161, H162, H163, H164, H165, H166, H167, H168, H169, H170, H171, H172, H173, H174, H175, H176, H177, H178, H179, H180, H181, H182, H183, H184, H185, H186, H187, H188, H189, H190, H191, H192: STAND-OFFTIGHT; STAND-OFF-TIGHT
J1, J5, J8, J11, J14, J17, J20, J23, J26, J29, J32, J35, J38, J41, J44, J47, J50, J53, J56, J59, J62, J65, J68, J71, J74, J77, J80, J83, J86, J89, J92, J95, J98, J101, J104, J107, J110, J113, J116, J119, J122, J125, J128, J131, J134, J137, J140, J143: Screw Terminal; SCREWTERMINAL-3.5MM-4
J2, J6, J9, J12, J15, J18, J21, J24, J27, J30, J33, J36, J39, J42, J45, J48, J51, J54, J57, J60, J63, J66, J69, J72, J75, J78, J81, J84, J87, J90, J93, J96, J99, J102, J105, J108, J111, J114, J117, J120, J123, J126, J129, J132, J135, J138, J141, J144: POWER_JACKPOWER_JACK_SLOT_COMBO; POWER_JACK_PTH_SLOT_BOTH
J3, J4, J7, J10, J13, J16, J19, J22, J25, J28, J31, J34, J37, J40, J43, J46, J49, J52, J55, J58, J61, J64, J67, J70, J73, J76, J79, J82, J85, J88, J91, J94, J97, J100, J103, J106, J109, J112, J115, J118, J121, J124, J127, J130, J133, J136, J139, J142: Breakout Headers; 1X05_NO_SILK
L1, L2, L3, L4, L5, L6, L7, L8, L9, L10, L11, L12, L13, L14, L15, L16, L17, L18, L19, L20, L21, L22, L23, L24, L25, L26, L27, L28, L29, L30, L31, L32, L33, L34, L35, L36, L37, L38, L39, L40, L41, L42, L43, L44, L45, L46, L47, L48: 2.2μH; INDUCTOR_4X4MM
LOGO1, LOGO4, LOGO7, LOGO10, LOGO13, LOGO16, LOGO19, LOGO22, LOGO25, LOGO28, LOGO31, LOGO34, LOGO37, LOGO40, LOGO43, LOGO46, LOGO49, LOGO52, LOGO55, LOGO58, LOGO61, LOGO64, LOGO67, LOGO70, LOGO73, LOGO76, LOGO79, LOGO82, LOGO85, LOGO88, LOGO91, LOGO94, LOGO97, LOGO100, LOGO103, LOGO106, LOGO109, LOGO112, LOGO115, LOGO118, LOGO121, LOGO124, LOGO127, LOGO130, LOGO133, LOGO136, LOGO139, LOGO142: OSHW-LOGOS; OSHW-LOGO-S
LOGO2, LOGO6, LOGO9, LOGO12, LOGO15, LOGO18, LOGO21, LOGO24, LOGO27, LOGO30, LOGO33, LOGO36, LOGO39, LOGO42, LOGO45, LOGO48, LOGO51, LOGO54, LOGO57, LOGO60, LOGO63, LOGO66, LOGO69, LOGO72, LOGO75, LOGO78, LOGO81, LOGO84, LOGO87, LOGO90, LOGO93, LOGO96, LOGO99, LOGO102, LOGO105, LOGO108, LOGO111, LOGO114, LOGO117, LOGO120, LOGO123, LOGO126, LOGO129, LOGO132, LOGO135, LOGO138, LOGO141, LOGO144: SFE_LOGO_NAME.1_INCH; SFE_LOGO_NAME_.1
LOGO3, LOGO5, LOGO8, LOGO11, LOGO14, LOGO17, LOGO20, LOGO23, LOGO26, LOGO29, LOGO32, LOGO35, LOGO38, LOGO41, LOGO44, LOGO47, LOGO50, LOGO53, LOGO56, LOGO59, LOGO62, LOGO65, LOGO68, LOGO71, LOGO74, LOGO77, LOGO80, LOGO83, LOGO86, LOGO89, LOGO92, LOGO95, LOGO98, LOGO101, LOGO104, LOGO107, LOGO110, LOGO113, LOGO116, LOGO119, LOGO122, LOGO125, LOGO128, LOGO131, LOGO134, LOGO137, LOGO140, LOGO143: SFE_LOGO_FLAME.1_INCH; SFE_LOGO_FLAME_.1
PWR, PWR1, PWR2, PWR3, PWR4, PWR5, PWR6, PWR7, PWR8, PWR9, PWR10, PWR11, PWR12, PWR13, PWR14, PWR15, PWR16, PWR17, PWR18, PWR19, PWR20, PWR21, PWR22, PWR23, PWR24, PWR25, PWR26, PWR27, PWR28, PWR29, PWR30, PWR31, PWR32, PWR33, PWR34, PWR35, PWR36, PWR37, PWR38, PWR39, PWR40, PWR41, PWR42, PWR43, PWR44, PWR45, PWR46, PWR47: JUMPER-SMT_2_NC_TRACE_SILK; SMT-JUMPER_2_NC_TRACE_SILK
R1, R5, R9, R13, R17, R21, R25, R29, R33, R37, R41, R45, R49, R53, R57, R61, R65, R69, R73, R77, R81, R85, R89, R93, R97, R101, R105, R109, R113, R117, R121, R125, R129, R133, R137, R141, R145, R149, R153, R157, R161, R165, R169, R173, R177, R181, R185, R189: 300k; 0603
R2, R6, R10, R14, R18, R22, R26, R30, R34, R38, R42, R46, R50, R54, R58, R62, R66, R70, R74, R78, R82, R86, R90, R94, R98, R102, R106, R110, R114, R118, R122, R126, R130, R134, R138, R142, R146, R150, R154, R158, R162, R166, R170, R174, R178, R182, R186, R190: 150k; 0603
R3, R7, R11, R15, R19, R23, R27, R31, R35, R39, R43, R47, R51, R55, R59, R63, R67, R71, R75, R79, R83, R87, R91, R95, R99, R103, R107, R111, R115, R119, R123, R127, R131, R135, R139, R143, R147, R151, R155, R159, R163, R167, R171, R175, R179, R183, R187, R191: 100; 0603
R4, R8, R12, R16, R20, R24, R28, R32, R36, R40, R44, R48, R52, R56, R60, R64, R68, R72, R76, R80, R84, R88, R92, R96, R100, R104, R108, R112, R116, R120, R124, R128, R132, R136, R140, R144, R148, R152, R156, R160, R164, R168, R172, R176, R180, R184, R188, R192: 100k; 0603
U1, U2, U3, U4, U5, U6, U7, U8, U9, U10, U11, U12, U13, U14, U15, U16, U17, U18, U19, U20, U21, U22, U23, U24, U25, U26, U27, U28, U29, U30, U31, U32, U33, U34, U35, U36, U37, U38, U39, U40, U41, U42, U43, U44, U45, U46, U47, U48: AP3429/A; SOT23-5
U$1, U$17, U$47, U$70, U$93, U$116, U$139, U$162, U$185, U$208, U$231, U$254, U$277, U$300, U$323, U$346, U$369, U$392, U$415, U$438, U$461, U$484, U$507, U$530, U$553, U$576, U$599, U$622, U$645, U$668, U$691, U$714, U$737, U$760, U$783, U$806, U$829, U$852, U$875, U$898, U$921, U$944, U$967, U$990, U$1013, U$1036, U$1059, U$1082: SFE_LOGO_FLAME_.1
U$2, U$18, U$48, U$71, U$94, U$117, U$140, U$163, U$186, U$209, U$232, U$255, U$278, U$301, U$324, U$347, U$370, U$393, U$416, U$439, U$462, U$485, U$508, U$531, U$554, U$577, U$600, U$623, U$646, U$669, U$692, U$715, U$738, U$761, U$784, U$807, U$830, U$853, U$876, U$899, U$922, U$945, U$968, U$991, U$1014, U$1037, U$1060, U$1083: BUCK_REGULATOR24
U$3, U$26, U$49, U$72, U$95, U$118, U$141, U$164, U$187, U$210, U$233, U$256, U$279, U$302, U$325, U$348, U$371, U$394, U$417, U$440, U$463, U$486, U$509, U$532, U$555, U$578, U$601, U$624, U$647, U$670, U$693, U$716, U$739, U$762, U$785, U$808, U$831, U$854, U$877, U$900, U$923, U$946, U$969, U$992, U$1015, U$1038, U$1061, U$1084: AP3429#A25
U$4, U$27, U$50, U$73, U$96, U$119, U$142, U$165, U$188, U$211, U$234, U$257, U$280, U$303, U$326, U$349, U$372, U$395, U$418, U$441, U$464, U$487, U$510, U$533, U$556, U$579, U$602, U$625, U$648, U$671, U$694, U$717, U$740, U$763, U$786, U$809, U$832, U$855, U$878, U$901, U$924, U$947, U$970, U$993, U$1016, U$1039, U$1062, U$1085: #VOUT#3431
U$5, U$6, U$28, U$29, U$51, U$52, U$74, U$75, U$97, U$98, U$120, U$121, U$143, U$144, U$166, U$167, U$189, U$190, U$212, U$213, U$235, U$236, U$258, U$259, U$281, U$282, U$304, U$305, U$327, U$328, U$350, U$351, U$373, U$374, U$396, U$397, U$419, U$420, U$442, U$443, U$465, U$466, U$488, U$489, U$511, U$512, U$534, U$535, U$557, U$558, U$580, U$581, U$603, U$604, U$626, U$627, U$649, U$650, U$672, U$673, U$695, U$696, U$718, U$719, U$741, U$742, U$764, U$765, U$787, U$788, U$810, U$811, U$833, U$834, U$856, U$857, U$879, U$880, U$902, U$903, U$925, U$926, U$948, U$949, U$971, U$972, U$994, U$995, U$1017, U$1018, U$1040, U$1041, U$1063, U$1064, U$1086, U$1087: #GND#3432
U$7, U$30, U$53, U$76, U$99, U$122, U$145, U$168, U$191, U$214, U$237, U$260, U$283, U$306, U$329, U$352, U$375, U$398, U$421, U$444, U$467, U$490, U$513, U$536, U$559, U$582, U$605, U$628, U$651, U$674, U$697, U$720, U$743, U$766, U$789, U$812, U$835, U$858, U$881, U$904, U$927, U$950, U$973, U$996, U$1019, U$1042, U$1065, U$1088: #VIN#3433
U$8, U$10, U$39, U$42, U$62, U$65, U$85, U$88, U$108, U$111, U$131, U$134, U$154, U$157, U$177, U$180, U$200, U$203, U$223, U$226, U$246, U$249, U$269, U$272, U$292, U$295, U$315, U$318, U$338, U$341, U$361, U$364, U$384, U$387, U$407, U$410, U$430, U$433, U$453, U$456, U$476, U$479, U$499, U$502, U$522, U$525, U$545, U$548, U$568, U$571, U$591, U$594, U$614, U$617, U$637, U$640, U$660, U$663, U$683, U$686, U$706, U$709, U$729, U$732, U$752, U$755, U$775, U$778, U$798, U$801, U$821, U$824, U$844, U$847, U$867, U$870, U$890, U$893, U$913, U$916, U$936, U$939, U$959, U$962, U$982, U$985, U$1005, U$1008, U$1028, U$1031, U$1051, U$1054, U$1074, U$1077, U$1097, U$1100: #GND#3446
U$9, U$15, U$38, U$44, U$61, U$67, U$84, U$90, U$107, U$113, U$130, U$136, U$153, U$159, U$176, U$182, U$199, U$205, U$222, U$228, U$245, U$251, U$268, U$274, U$291, U$297, U$314, U$320, U$337, U$343, U$360, U$366, U$383, U$389, U$406, U$412, U$429, U$435, U$452, U$458, U$475, U$481, U$498, U$504, U$521, U$527, U$544, U$550, U$567, U$573, U$590, U$596, U$613, U$619, U$636, U$642, U$659, U$665, U$682, U$688, U$705, U$711, U$728, U$734, U$751, U$757, U$774, U$780, U$797, U$803, U$820, U$826, U$843, U$849, U$866, U$872, U$889, U$895, U$912, U$918, U$935, U$941, U$958, U$964, U$981, U$987, U$1004, U$1010, U$1027, U$1033, U$1050, U$1056, U$1073, U$1079, U$1096, U$1102: #VIN#3445
U$11, U$13, U$40, U$43, U$63, U$66, U$86, U$89, U$109, U$112, U$132, U$135, U$155, U$158, U$178, U$181, U$201, U$204, U$224, U$227, U$247, U$250, U$270, U$273, U$293, U$296, U$316, U$319, U$339, U$342, U$362, U$365, U$385, U$388, U$408, U$411, U$431, U$434, U$454, U$457, U$477, U$480, U$500, U$503, U$523, U$526, U$546, U$549, U$569, U$572, U$592, U$595, U$615, U$618, U$638, U$641, U$661, U$664, U$684, U$687, U$707, U$710, U$730, U$733, U$753, U$756, U$776, U$779, U$799, U$802, U$822, U$825, U$845, U$848, U$868, U$871, U$891, U$894, U$914, U$917, U$937, U$940, U$960, U$963, U$983, U$986, U$1006, U$1009, U$1029, U$1032, U$1052, U$1055, U$1075, U$1078, U$1098, U$1101: #VOUT#3447
U$12, U$41, U$64, U$87, U$110, U$133, U$156, U$179, U$202, U$225, U$248, U$271, U$294, U$317, U$340, U$363, U$386, U$409, U$432, U$455, U$478, U$501, U$524, U$547, U$570, U$593, U$616, U$639, U$662, U$685, U$708, U$731, U$754, U$777, U$800, U$823, U$846, U$869, U$892, U$915, U$938, U$961, U$984, U$1007, U$1030, U$1053, U$1076, U$1099: #EN#3448
U$14, U$45, U$68, U$91, U$114, U$137, U$160, U$183, U$206, U$229, U$252, U$275, U$298, U$321, U$344, U$367, U$390, U$413, U$436, U$459, U$482, U$505, U$528, U$551, U$574, U$597, U$620, U$643, U$666, U$689, U$712, U$735, U$758, U$781, U$804, U$827, U$850, U$873, U$896, U$919, U$942, U$965, U$988, U$1011, U$1034, U$1057, U$1080, U$1103: #PWR#3451
U$16, U$46, U$69, U$92, U$115, U$138, U$161, U$184, U$207, U$230, U$253, U$276, U$299, U$322, U$345, U$368, U$391, U$414, U$437, U$460, U$483, U$506, U$529, U$552, U$575, U$598, U$621, U$644, U$667, U$690, U$713, U$736, U$759, U$782, U$805, U$828, U$851, U$874, U$897, U$920, U$943, U$966, U$989, U$1012, U$1035, U$1058, U$1081, U$1104: BUCK_REGULATOR_AP3429#A3453
U$19, U$35, U$58, U$81, U$104, U$127, U$150, U$173, U$196, U$219, U$242, U$265, U$288, U$311, U$334, U$357, U$380, U$403, U$426, U$449, U$472, U$495, U$518, U$541, U$564, U$587, U$610, U$633, U$656, U$679, U$702, U$725, U$748, U$771, U$794, U$817, U$840, U$863, U$886, U$909, U$932, U$955, U$978, U$1001, U$1024, U$1047, U$1070, U$1093: 1#8V3441
U$20, U$36, U$59, U$82, U$105, U$128, U$151, U$174, U$197, U$220, U$243, U$266, U$289, U$312, U$335, U$358, U$381, U$404, U$427, U$450, U$473, U$496, U$519, U$542, U$565, U$588, U$611, U$634, U$657, U$680, U$703, U$726, U$749, U$772, U$795, U$818, U$841, U$864, U$887, U$910, U$933, U$956, U$979, U$1002, U$1025, U$1048, U$1071, U$1094: PWR3441
U$21, U$31, U$54, U$77, U$100, U$123, U$146, U$169, U$192, U$215, U$238, U$261, U$284, U$307, U$330, U$353, U$376, U$399, U$422, U$445, U$468, U$491, U$514, U$537, U$560, U$583, U$606, U$629, U$652, U$675, U$698, U$721, U$744, U$767, U$790, U$813, U$836, U$859, U$882, U$905, U$928, U$951, U$974, U$997, U$1020, U$1043, U$1066, U$1089: #VOUT#3437
U$22, U$32, U$55, U$78, U$101, U$124, U$147, U$170, U$193, U$216, U$239, U$262, U$285, U$308, U$331, U$354, U$377, U$400, U$423, U$446, U$469, U$492, U$515, U$538, U$561, U$584, U$607, U$630, U$653, U$676, U$699, U$722, U$745, U$768, U$791, U$814, U$837, U$860, U$883, U$906, U$929, U$952, U$975, U$998, U$1021, U$1044, U$1067, U$1090: #VIN#3438
U$23, U$34, U$57, U$80, U$103, U$126, U$149, U$172, U$195, U$218, U$241, U$264, U$287, U$310, U$333, U$356, U$379, U$402, U$425, U$448, U$471, U$494, U$517, U$540, U$563, U$586, U$609, U$632, U$655, U$678, U$701, U$724, U$747, U$770, U$793, U$816, U$839, U$862, U$885, U$908, U$931, U$954, U$977, U$1000, U$1023, U$1046, U$1069, U$1092: 3#3V3441
U$24, U$33, U$56, U$79, U$102, U$125, U$148, U$171, U$194, U$217, U$240, U$263, U$286, U$309, U$332, U$355, U$378, U$401, U$424, U$447, U$470, U$493, U$516, U$539, U$562, U$585, U$608, U$631, U$654, U$677, U$700, U$723, U$746, U$769, U$792, U$815, U$838, U$861, U$884, U$907, U$930, U$953, U$976, U$999, U$1022, U$1045, U$1068, U$1091: #GND#3439
U$25, U$37, U$60, U$83, U$106, U$129, U$152, U$175, U$198, U$221, U$244, U$267, U$290, U$313, U$336, U$359, U$382, U$405, U$428, U$451, U$474, U$497, U$520, U$543, U$566, U$589, U$612, U$635, U$658, U$681, U$704, U$727, U$750, U$773, U$796, U$819, U$842, U$865, U$888, U$911, U$934, U$957, U$980, U$1003, U$1026, U$1049, U$1072, U$1095: #EN#3443

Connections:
EN: J3.1, R4.1, U1.1
EN1: J4.1, R8.1, U2.1
EN2: J7.1, R12.1, U3.1
EN3: J10.1, R16.1, U4.1
EN4: J13.1, R20.1, U5.1
EN5: J16.1, R24.1, U6.1
EN6: J19.1, R28.1, U7.1
EN7: J22.1, R32.1, U8.1
EN8: J25.1, R36.1, U9.1
EN9: J28.1, R40.1, U10.1
EN10: J31.1, R44.1, U11.1
EN11: J34.1, R48.1, U12.1
EN12: J37.1, R52.1, U13.1
EN13: J40.1, R56.1, U14.1
EN14: J43.1, R60.1, U15.1
EN15: J46.1, R64.1, U16.1
EN16: J49.1, R68.1, U17.1
EN17: J52.1, R72.1, U18.1
EN18: J55.1, R76.1, U19.1
EN19: J58.1, R80.1, U20.1
EN20: J61.1, R84.1, U21.1
EN21: J64.1, R88.1, U22.1
EN22: J67.1, R92.1, U23.1
EN23: J70.1, R96.1, U24.1
EN24: J73.1, R100.1, U25.1
EN25: J76.1, R104.1, U26.1
EN26: J79.1, R108.1, U27.1
EN27: J82.1, R112.1, U28.1
EN28: J85.1, R116.1, U29.1
EN29: J88.1, R120.1, U30.1
EN30: J91.1, R124.1, U31.1
EN31: J94.1, R128.1, U32.1
EN32: J97.1, R132.1, U33.1
EN33: J100.1, R136.1, U34.1
EN34: J103.1, R140.1, U35.1
EN35: J106.1, R144.1, U36.1
EN36: J109.1, R148.1, U37.1
EN37: J112.1, R152.1, U38.1
EN38: J115.1, R156.1, U39.1
EN39: J118.1, R160.1, U40.1
EN40: J121.1, R164.1, U41.1
EN41: J124.1, R168.1, U42.1
EN42: J127.1, R172.1, U43.1
EN43: J130.1, R176.1, U44.1
EN44: J133.1, R180.1, U45.1
EN45: J136.1, R184.1, U46.1
EN46: J139.1, R188.1, U47.1
EN47: J142.1, R192.1, U48.1
GND: C1.2, C3.2, C4.2, C5.2, C6.2, D1.C, J1.2, J1.3, J2.GND, J3.3, J3.4, R2.1, U1.2
GND1: C8.2, C9.2, C10.2, C11.2, C12.2, D2.C, J4.3, J4.4, J5.2, J5.3, J6.GND, R6.1, U2.2
GND2: C14.2, C15.2, C16.2, C17.2, C18.2, D3.C, J7.3, J7.4, J8.2, J8.3, J9.GND, R10.1, U3.2
GND3: C20.2, C21.2, C22.2, C23.2, C24.2, D4.C, J10.3, J10.4, J11.2, J11.3, J12.GND, R14.1, U4.2
GND4: C26.2, C27.2, C28.2, C29.2, C30.2, D5.C, J13.3, J13.4, J14.2, J14.3, J15.GND, R18.1, U5.2
GND5: C32.2, C33.2, C34.2, C35.2, C36.2, D6.C, J16.3, J16.4, J17.2, J17.3, J18.GND, R22.1, U6.2
GND6: C38.2, C39.2, C40.2, C41.2, C42.2, D7.C, J19.3, J19.4, J20.2, J20.3, J21.GND, R26.1, U7.2
GND7: C44.2, C45.2, C46.2, C47.2, C48.2, D8.C, J22.3, J22.4, J23.2, J23.3, J24.GND, R30.1, U8.2
GND8: C50.2, C51.2, C52.2, C53.2, C54.2, D9.C, J25.3, J25.4, J26.2, J26.3, J27.GND, R34.1, U9.2
GND9: C56.2, C57.2, C58.2, C59.2, C60.2, D10.C, J28.3, J28.4, J29.2, J29.3, J30.GND, R38.1, U10.2
GND10: C62.2, C63.2, C64.2, C65.2, C66.2, D11.C, J31.3, J31.4, J32.2, J32.3, J33.GND, R42.1, U11.2
GND11: C68.2, C69.2, C70.2, C71.2, C72.2, D12.C, J34.3, J34.4, J35.2, J35.3, J36.GND, R46.1, U12.2
GND12: C74.2, C75.2, C76.2, C77.2, C78.2, D13.C, J37.3, J37.4, J38.2, J38.3, J39.GND, R50.1, U13.2
GND13: C80.2, C81.2, C82.2, C83.2, C84.2, D14.C, J40.3, J40.4, J41.2, J41.3, J42.GND, R54.1, U14.2
GND14: C86.2, C87.2, C88.2, C89.2, C90.2, D15.C, J43.3, J43.4, J44.2, J44.3, J45.GND, R58.1, U15.2
GND15: C92.2, C93.2, C94.2, C95.2, C96.2, D16.C, J46.3, J46.4, J47.2, J47.3, J48.GND, R62.1, U16.2
GND16: C98.2, C99.2, C100.2, C101.2, C102.2, D17.C, J49.3, J49.4, J50.2, J50.3, J51.GND, R66.1, U17.2
GND17: C104.2, C105.2, C106.2, C107.2, C108.2, D18.C, J52.3, J52.4, J53.2, J53.3, J54.GND, R70.1, U18.2
GND18: C110.2, C111.2, C112.2, C113.2, C114.2, D19.C, J55.3, J55.4, J56.2, J56.3, J57.GND, R74.1, U19.2
GND19: C116.2, C117.2, C118.2, C119.2, C120.2, D20.C, J58.3, J58.4, J59.2, J59.3, J60.GND, R78.1, U20.2
GND20: C122.2, C123.2, C124.2, C125.2, C126.2, D21.C, J61.3, J61.4, J62.2, J62.3, J63.GND, R82.1, U21.2
GND21: C128.2, C129.2, C130.2, C131.2, C132.2, D22.C, J64.3, J64.4, J65.2, J65.3, J66.GND, R86.1, U22.2
GND22: C134.2, C135.2, C136.2, C137.2, C138.2, D23.C, J67.3, J67.4, J68.2, J68.3, J69.GND, R90.1, U23.2
GND23: C140.2, C141.2, C142.2, C143.2, C144.2, D24.C, J70.3, J70.4, J71.2, J71.3, J72.GND, R94.1, U24.2
GND24: C146.2, C147.2, C148.2, C149.2, C150.2, D25.C, J73.3, J73.4, J74.2, J74.3, J75.GND, R98.1, U25.2
GND25: C152.2, C153.2, C154.2, C155.2, C156.2, D26.C, J76.3, J76.4, J77.2, J77.3, J78.GND, R102.1, U26.2
GND26: C158.2, C159.2, C160.2, C161.2, C162.2, D27.C, J79.3, J79.4, J80.2, J80.3, J81.GND, R106.1, U27.2
GND27: C164.2, C165.2, C166.2, C167.2, C168.2, D28.C, J82.3, J82.4, J83.2, J83.3, J84.GND, R110.1, U28.2
GND28: C170.2, C171.2, C172.2, C173.2, C174.2, D29.C, J85.3, J85.4, J86.2, J86.3, J87.GND, R114.1, U29.2
GND29: C176.2, C177.2, C178.2, C179.2, C180.2, D30.C, J88.3, J88.4, J89.2, J89.3, J90.GND, R118.1, U30.2
GND30: C182.2, C183.2, C184.2, C185.2, C186.2, D31.C, J91.3, J91.4, J92.2, J92.3, J93.GND, R122.1, U31.2
GND31: C188.2, C189.2, C190.2, C191.2, C192.2, D32.C, J94.3, J94.4, J95.2, J95.3, J96.GND, R126.1, U32.2
GND32: C194.2, C195.2, C196.2, C197.2, C198.2, D33.C, J97.3, J97.4, J98.2, J98.3, J99.GND, R130.1, U33.2
GND33: C200.2, C201.2, C202.2, C203.2, C204.2, D34.C, J100.3, J100.4, J101.2, J101.3, J102.GND, R134.1, U34.2
GND34: C206.2, C207.2, C208.2, C209.2, C210.2, D35.C, J103.3, J103.4, J104.2, J104.3, J105.GND, R138.1, U35.2
GND35: C212.2, C213.2, C214.2, C215.2, C216.2, D36.C, J106.3, J106.4, J107.2, J107.3, J108.GND, R142.1, U36.2
GND36: C218.2, C219.2, C220.2, C221.2, C222.2, D37.C, J109.3, J109.4, J110.2, J110.3, J111.GND, R146.1, U37.2
GND37: C224.2, C225.2, C226.2, C227.2, C228.2, D38.C, J112.3, J112.4, J113.2, J113.3, J114.GND, R150.1, U38.2
GND38: C230.2, C231.2, C232.2, C233.2, C234.2, D39.C, J115.3, J115.4, J116.2, J116.3, J117.GND, R154.1, U39.2
GND39: C236.2, C237.2, C238.2, C239.2, C240.2, D40.C, J118.3, J118.4, J119.2, J119.3, J120.GND, R158.1, U40.2
GND40: C242.2, C243.2, C244.2, C245.2, C246.2, D41.C, J121.3, J121.4, J122.2, J122.3, J123.GND, R162.1, U41.2
GND41: C248.2, C249.2, C250.2, C251.2, C252.2, D42.C, J124.3, J124.4, J125.2, J125.3, J126.GND, R166.1, U42.2
GND42: C254.2, C255.2, C256.2, C257.2, C258.2, D43.C, J127.3, J127.4, J128.2, J128.3, J129.GND, R170.1, U43.2
GND43: C260.2, C261.2, C262.2, C263.2, C264.2, D44.C, J130.3, J130.4, J131.2, J131.3, J132.GND, R174.1, U44.2
GND44: C266.2, C267.2, C268.2, C269.2, C270.2, D45.C, J133.3, J133.4, J134.2, J134.3, J135.GND, R178.1, U45.2
GND45: C272.2, C273.2, C274.2, C275.2, C276.2, D46.C, J136.3, J136.4, J137.2, J137.3, J138.GND, R182.1, U46.2
GND46: C278.2, C279.2, C280.2, C281.2, C282.2, D47.C, J139.3, J139.4, J140.2, J140.3, J141.GND, R186.1, U47.2
GND47: C284.2, C285.2, C286.2, C287.2, C288.2, D48.C, J142.3, J142.4, J143.2, J143.3, J144.GND, R190.1, U48.2
unnamed: L1.P$1, U1.3
unnamed: C2.2, R1.1, R2.2, U1.5
unnamed: PWR.1, R3.2
unnamed: D1.A, R3.1
unnamed: L2.P$1, U2.3
unnamed: C7.2, R5.1, R6.2, U2.5
unnamed: PWR1.1, R7.2
unnamed: D2.A, R7.1
unnamed: L3.P$1, U3.3
unnamed: C13.2, R9.1, R10.2, U3.5
unnamed: PWR2.1, R11.2
unnamed: D3.A, R11.1
unnamed: L4.P$1, U4.3
unnamed: C19.2, R13.1, R14.2, U4.5
unnamed: PWR3.1, R15.2
unnamed: D4.A, R15.1
unnamed: L5.P$1, U5.3
unnamed: C25.2, R17.1, R18.2, U5.5
unnamed: PWR4.1, R19.2
unnamed: D5.A, R19.1
unnamed: L6.P$1, U6.3
unnamed: C31.2, R21.1, R22.2, U6.5
unnamed: PWR5.1, R23.2
unnamed: D6.A, R23.1
unnamed: L7.P$1, U7.3
unnamed: C37.2, R25.1, R26.2, U7.5
unnamed: PWR6.1, R27.2
unnamed: D7.A, R27.1
unnamed: L8.P$1, U8.3
unnamed: C43.2, R29.1, R30.2, U8.5
unnamed: PWR7.1, R31.2
unnamed: D8.A, R31.1
unnamed: L9.P$1, U9.3
unnamed: C49.2, R33.1, R34.2, U9.5
unnamed: PWR8.1, R35.2
unnamed: D9.A, R35.1
unnamed: L10.P$1, U10.3
unnamed: C55.2, R37.1, R38.2, U10.5
unnamed: PWR9.1, R39.2
unnamed: D10.A, R39.1
unnamed: L11.P$1, U11.3
unnamed: C61.2, R41.1, R42.2, U11.5
unnamed: PWR10.1, R43.2
unnamed: D11.A, R43.1
unnamed: L12.P$1, U12.3
unnamed: C67.2, R45.1, R46.2, U12.5
unnamed: PWR11.1, R47.2
unnamed: D12.A, R47.1
unnamed: L13.P$1, U13.3
unnamed: C73.2, R49.1, R50.2, U13.5
unnamed: PWR12.1, R51.2
unnamed: D13.A, R51.1
unnamed: L14.P$1, U14.3
unnamed: C79.2, R53.1, R54.2, U14.5
unnamed: PWR13.1, R55.2
unnamed: D14.A, R55.1
unnamed: L15.P$1, U15.3
unnamed: C85.2, R57.1, R58.2, U15.5
unnamed: PWR14.1, R59.2
unnamed: D15.A, R59.1
unnamed: L16.P$1, U16.3
unnamed: C91.2, R61.1, R62.2, U16.5
unnamed: PWR15.1, R63.2
unnamed: D16.A, R63.1
unnamed: L17.P$1, U17.3
unnamed: C97.2, R65.1, R66.2, U17.5
unnamed: PWR16.1, R67.2
unnamed: D17.A, R67.1
unnamed: L18.P$1, U18.3
unnamed: C103.2, R69.1, R70.2, U18.5
unnamed: PWR17.1, R71.2
unnamed: D18.A, R71.1
unnamed: L19.P$1, U19.3
unnamed: C109.2, R73.1, R74.2, U19.5
unnamed: PWR18.1, R75.2
unnamed: D19.A, R75.1
unnamed: L20.P$1, U20.3
unnamed: C115.2, R77.1, R78.2, U20.5
unnamed: PWR19.1, R79.2
unnamed: D20.A, R79.1
unnamed: L21.P$1, U21.3
unnamed: C121.2, R81.1, R82.2, U21.5
unnamed: PWR20.1, R83.2
unnamed: D21.A, R83.1
unnamed: L22.P$1, U22.3
unnamed: C127.2, R85.1, R86.2, U22.5
unnamed: PWR21.1, R87.2
unnamed: D22.A, R87.1
unnamed: L23.P$1, U23.3
unnamed: C133.2, R89.1, R90.2, U23.5
unnamed: PWR22.1, R91.2
unnamed: D23.A, R91.1
unnamed: L24.P$1, U24.3
unnamed: C139.2, R93.1, R94.2, U24.5
unnamed: PWR23.1, R95.2
unnamed: D24.A, R95.1
unnamed: L25.P$1, U25.3
unnamed: C145.2, R97.1, R98.2, U25.5
unnamed: PWR24.1, R99.2
unnamed: D25.A, R99.1
unnamed: L26.P$1, U26.3
unnamed: C151.2, R101.1, R102.2, U26.5
unnamed: PWR25.1, R103.2
unnamed: D26.A, R103.1
unnamed: L27.P$1, U27.3
unnamed: C157.2, R105.1, R106.2, U27.5
unnamed: PWR26.1, R107.2
unnamed: D27.A, R107.1
unnamed: L28.P$1, U28.3
unnamed: C163.2, R109.1, R110.2, U28.5
unnamed: PWR27.1, R111.2
unnamed: D28.A, R111.1
unnamed: L29.P$1, U29.3
unnamed: C169.2, R113.1, R114.2, U29.5
unnamed: PWR28.1, R115.2
unnamed: D29.A, R115.1
unnamed: L30.P$1, U30.3
unnamed: C175.2, R117.1, R118.2, U30.5
unnamed: PWR29.1, R119.2
unnamed: D30.A, R119.1
unnamed: L31.P$1, U31.3
unnamed: C181.2, R121.1, R122.2, U31.5
unnamed: PWR30.1, R123.2
unnamed: D31.A, R123.1
unnamed: L32.P$1, U32.3
unnamed: C187.2, R125.1, R126.2, U32.5
unnamed: PWR31.1, R127.2
unnamed: D32.A, R127.1
unnamed: L33.P$1, U33.3
unnamed: C193.2, R129.1, R130.2, U33.5
unnamed: PWR32.1, R131.2
unnamed: D33.A, R131.1
unnamed: L34.P$1, U34.3
unnamed: C199.2, R133.1, R134.2, U34.5
unnamed: PWR33.1, R135.2
unnamed: D34.A, R135.1
unnamed: L35.P$1, U35.3
unnamed: C205.2, R137.1, R138.2, U35.5
unnamed: PWR34.1, R139.2
unnamed: D35.A, R139.1
unnamed: L36.P$1, U36.3
unnamed: C211.2, R141.1, R142.2, U36.5
unnamed: PWR35.1, R143.2
unnamed: D36.A, R143.1
unnamed: L37.P$1, U37.3
unnamed: C217.2, R145.1, R146.2, U37.5
unnamed: PWR36.1, R147.2
unnamed: D37.A, R147.1
unnamed: L38.P$1, U38.3
unnamed: C223.2, R149.1, R150.2, U38.5
unnamed: PWR37.1, R151.2
unnamed: D38.A, R151.1
unnamed: L39.P$1, U39.3
unnamed: C229.2, R153.1, R154.2, U39.5
unnamed: PWR38.1, R155.2
unnamed: D39.A, R155.1
unnamed: L40.P$1, U40.3
unnamed: C235.2, R157.1, R158.2, U40.5
unnamed: PWR39.1, R159.2
unnamed: D40.A, R159.1
unnamed: L41.P$1, U41.3
unnamed: C241.2, R161.1, R162.2, U41.5
unnamed: PWR40.1, R163.2
unnamed: D41.A, R163.1
unnamed: L42.P$1, U42.3
unnamed: C247.2, R165.1, R166.2, U42.5
unnamed: PWR41.1, R167.2
unnamed: D42.A, R167.1
unnamed: L43.P$1, U43.3
unnamed: C253.2, R169.1, R170.2, U43.5
unnamed: PWR42.1, R171.2
unnamed: D43.A, R171.1
unnamed: L44.P$1, U44.3
unnamed: C259.2, R173.1, R174.2, U44.5
unnamed: PWR43.1, R175.2
unnamed: D44.A, R175.1
unnamed: L45.P$1, U45.3
unnamed: C265.2, R177.1, R178.2, U45.5
unnamed: PWR44.1, R179.2
unnamed: D45.A, R179.1
unnamed: L46.P$1, U46.3
unnamed: C271.2, R181.1, R182.2, U46.5
unnamed: PWR45.1, R183.2
unnamed: D46.A, R183.1
unnamed: L47.P$1, U47.3
unnamed: C277.2, R185.1, R186.2, U47.5
unnamed: PWR46.1, R187.2
unnamed: D47.A, R187.1
unnamed: L48.P$1, U48.3
unnamed: C283.2, R189.1, R190.2, U48.5
unnamed: PWR47.1, R191.2
unnamed: D48.A, R191.1
VIN: C1.1, J1.1, J2.PWR, J3.2, R4.2, U1.4
VIN1: C8.1, J4.2, J5.1, J6.PWR, R8.2, U2.4
VIN2: C14.1, J7.2, J8.1, J9.PWR, R12.2, U3.4
VIN3: C20.1, J10.2, J11.1, J12.PWR, R16.2, U4.4
VIN4: C26.1, J13.2, J14.1, J15.PWR, R20.2, U5.4
VIN5: C32.1, J16.2, J17.1, J18.PWR, R24.2, U6.4
VIN6: C38.1, J19.2, J20.1, J21.PWR, R28.2, U7.4
VIN7: C44.1, J22.2, J23.1, J24.PWR, R32.2, U8.4
VIN8: C50.1, J25.2, J26.1, J27.PWR, R36.2, U9.4
VIN9: C56.1, J28.2, J29.1, J30.PWR, R40.2, U10.4
VIN10: C62.1, J31.2, J32.1, J33.PWR, R44.2, U11.4
VIN11: C68.1, J34.2, J35.1, J36.PWR, R48.2, U12.4
VIN12: C74.1, J37.2, J38.1, J39.PWR, R52.2, U13.4
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

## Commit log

2022-12-05 Created schematic, updated README, deleted/moved folders
    Added the schematic to the project, along with starting to add parts, aesthetics, and attributes. Updated the README with project information, and moved around file folders/deleted the unneeded folde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
    [Buck_Regulator_AP3429A.sch]
2022-12-08 Addition of App Note, Updates to Schematic
    Added connectors, power led, and main ic circuit with correctly rated components. The application note was added for the new product that Diodes Inc. sells, but it is the same exact part as the AP3429A but with a lower current limit (from 2A to 1A)
    [Buck_Regulator_AP3429A.sch]
2022-12-08 Update Buck_Regulator_AP3429A.sch
    Attributes added for parts missing that information, finished first draft of initial schematic for 1.8V output, added further notation on what to change for 3.3V output instead of the 1.8V output.
    [Buck_Regulator_AP3429A.sch]
2022-12-09 Created Board file and cleaned up schematic
    Added notation jumpers for 3.3V or 1.8V board, created board file and adjusted components to fit onto the board in a 1x1 form factor.
    [Buck_Regulator_AP3429A.brd, Buck_Regulator_AP3429A.sch]
2022-12-14 Updates to project
    Schematic: Changed indicator pads for soldering which version of board, added further notation, updated Power Jack device in local library.
    Layout: Added power polygons and stitching vias to appropriate areas, finished routing, adjusted Power Jack to be double sided now, fixed silkscreen notation, adjusted version number, worked through design errors.
    [Buck_Regulator_AP3429A.brd, Buck_Regulator_AP3429A.sch]
2022-12-15 v01 Design Review commit
    Small changes were made after running the python checklist. Added more GND vias, added the Power LED silkscreen indicator, updated dimension layer line width, adjusted polygons for better GND pour co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
    [Buck_Regulator_AP3429A.brd]
2022-12-15 heat sink addition - v01 design review
    Changed the SparkFun logo on the backside of the board and separated the name and flame; added an area on the backside for the heatsink to be added; adjusted silkscreen and components on backside acc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
    [Buck_Regulator_AP3429A.brd, Buck_Regulator_AP3429A.sch]
2022-12-16 Updates from design review
    Restructured file folder and project structure to have design files with two different eagle projects within the same github folder; adjusted components on layout for better loop stability; moved indicator for which version of the board to the bottom by the name; changed capacitor values to be better rated and size; added milling layer to power jack; adjusted thermals on output inductor; added more GND vias
    [Buck_Regulator_AP3429A_1V8.brd, Buck_Regulator_AP3429A_1V8.sch, Buck_Regulator_AP3429A_3V3.sch]
2022-12-16 Updated 3.3V files to be the same as 1.8V
    Changed the 3 resistors (R1, R2, R3) and placed them in the same location as the 1.8V board files.
    [Buck_Regulator_AP3429A_3V3.brd, Buck_Regulator_AP3429A_3V3.sch]
2022-12-19 Nudge traces for better GND pour connection on BRD
    Moved some traces for a better GND pour on the top layer.
    [Buck_Regulator_AP3429A_1V8.brd, Buck_Regulator_AP3429A_3V3.brd]
2022-12-19 Added correct measurements
    [Buck_Regulator_AP3429A_1V8.brd, Buck_Regulator_AP3429A_3V3.brd]
2022-12-19 Further design review changes - v01
    Added selective solder path to Document layer for the terminal block; moved the silkscreen name on the front to not be covered by the mounting hole anymore when a user uses a screw; nudges the LED po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
    [Buck_Regulator_AP3429A_1V8.brd, Buck_Regulator_AP3429A_3V3.brd]
2022-12-19 Added files for ordering protos
    Ordering proto type boards - added gerbers and .zip file
    [Buck_Regulator_AP3429A_1V8.GBL, Buck_Regulator_AP3429A_1V8.GBO, Buck_Regulator_AP3429A_1V8.GBP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]
2023-02-02 Updated files for design review
    Changed the version number on the board file to be V10 instead of V01, then changed the footprint of the power jack on each side of the board to swap the sides of the exposed copper on the groundbreak pins for easier soldering.
    [Buck_Regulator_AP3429A_1V8.brd, Buck_Regulator_AP3429A_1V8.sch, Buck_Regulator_AP3429A_3V3.brd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]
2023-02-02 Changed version number in schematic, adjusted components
    Moved around some silkscreen in order for easier reading on the backside; changed the version number in the schematic to v10
    [Buck_Regulator_AP3429A_1V8.brd, Buck_Regulator_AP3429A_1V8.sch, Buck_Regulator_AP3429A_3V3.brd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]
2023-02-02 Added 2 more output capacitors
    Added more output capacitance to match ALC block - there was some ripple detected during testing so adding these should eliminate that. Adjusted the components on the board accordingly then matched t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
    [Buck_Regulator_AP3429A_1V8.brd, Buck_Regulator_AP3429A_1V8.sch, Buck_Regulator_AP3429A_3V3.brd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]
2023-02-03 Added panelized files and gerbers
    Panelized the file to match the other buck regulator. Moved the files out of the hardware folders for consistency and easy finding.
    [Buck_Regulator_AP3429A_1V8-Panel.brd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]
2023-02-03 Design Review changes
    Cleaned up 1.8V Hardware folder by deleting unneeded files, adjusted schematic notes for easier reading, deleted extraneous measures, adjusted GND via sizes to be the same size (15mil), adjusted some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
    [Buck_Regulator_AP3429A_1V8-Panel.brd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]
2023-02-06 Adjusted power jack for panelizing
    There was an issue with overhanging silkscreen for the powerjack since the part is usually populated - the part is not populated for this specific part. This was changed from the device all the way through the panelized files.
    [Buck_Regulator_AP3429A_1V8-Panel.brd, Buck_Regulator_AP3429A_1V8.brd, Buck_Regulator_AP3429A_1V8.sch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]
2023-02-06 Updated panelized files
    Adjusted via to no longer be in the way of the bStop on the back for the thermal pad on the backside. Included ordering instructions on the brd files for both 1.8V and 3.3V
    [Buck_Regulator_AP3429A_1V8-Panel.brd, Buck_Regulator_AP3429A_1V8.brd, Buck_Regulator_AP3429A_3V3-Panel.brd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]
2023-02-06 Adjusted ordering instructions
    Changed the ordering instructions to further detail the aspects of the board - 2-layer, 1.6mm thickness, 1oz copper
    [Buck_Regulator_AP3429A_1V8.brd, Buck_Regulator_AP3429A_3V3.brd]
2023-02-06 Deleted unneeded files
    No longer needed these files since they were for ordering individual boards for prototyping
    [DRILEGEND.CFG]
2023-02-07 Updated dimensions
    Moved the thermal pad dimensions to Layer 49 Reference for easier/cleaner reading for the user. This may change, but keeping consistent with the other Buck Regulator.
    [Buck_Regulator_AP3429A_1V8.brd, Buck_Regulator_AP3429A_3V3.brd]
2023-03-09 V11 Design Update
    Added 100k resistor to pull EN high to VIN for an easier plug and play application.
    [Buck_Regulator_AP3429A_1V8-Panel.brd, Buck_Regulator_AP3429A_1V8.brd, Buck_Regulator_AP3429A_1V8.sch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]
2023-03-09 V11 Design updates - remove unneeded files
    Removed unneeded file that appeared in the Documentation folder (???)
    [ESP32_BLDC_Motor_Driver.sch]
2023-04-04 Updated board files
2023-04-04 LiPo Battery Info
    Added information for powering the boards with a batteries
2023-04-04 Hookup Guide Pics
    Updated pictures for the hardware assembly and load test sections
2023-04-07 Update documentation
    Add LiPo battery information
    Added in thermal profiling charts
    Added in quiescent current measurements

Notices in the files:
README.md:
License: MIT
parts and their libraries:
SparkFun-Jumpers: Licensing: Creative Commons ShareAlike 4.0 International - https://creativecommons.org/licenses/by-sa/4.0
